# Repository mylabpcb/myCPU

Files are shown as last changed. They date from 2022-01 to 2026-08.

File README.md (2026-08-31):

> This release is obsolete, use only for learning purposes. We are working on the myCPU16 R2 with many improvements.

### Welcome to the myCPU project!.

All information is on the project site at: 
<a href="https://mycpu.mylabpcb.com/" target="_blank">myCPU project site (https://mycpu.mylabpcb.com/)</a>

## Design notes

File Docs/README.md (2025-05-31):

### Technical documentation of the myCPU Project

Here you can find all the schematics, dimensional views, BOM and assembly lists related to each module of myCPU. Including separated route views for each pcb layer.

All of this documentation is included in the printable version of the myCPU Book.

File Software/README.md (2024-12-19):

### Useful software tools to manage and configure myCPU.

Under the EncoderCLI folder you can find the Command Line tool to generate a binary file with the encoded microprogramming from the myCPU ISA definition file. 

You can use that file to write the encoded microprogramming, generated by the Encoder CLI, to the Instruction Decoder memories using an EEProm programmer or to write the simulator decoder memories.

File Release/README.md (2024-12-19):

### Useful check list about myCPU16 final release versions
This list shows the final PCB release versions of the myCPU, is useful to track the Kit release in case of updated releases of existing PCBs.

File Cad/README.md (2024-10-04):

### Useful CAD designs of tools and build help parts for myCPU

All are prepared for 3D print.

Unplugger tool is essential to manage myCPU modules when unplug from the main base stucture.
Separators are needed to build a rigid myCPU structura capable to support the modules exchange.
Display separator are used to isolate electrically the displays from the modules.

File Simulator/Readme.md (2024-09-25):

### Logisim Evolution myCPU simulator

1 For use customasm with logisim to create memory binaries from assembly code
```
customasm -f logisim8

```

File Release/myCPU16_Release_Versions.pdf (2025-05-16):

BUS Module 11 | Layout/Single Connector 5/3
RESET IO 11 | BUS Manager 9
CSM 10 | CLOCK 23
I.DECODER 9 | PC 15
FLAGS/SEQ 14 | I.REGISTER 11
REG C 8 | REG A 10
MAR 5 | ALU 19
SRAM 15 | REG B 10
DISPLAY 4 DIG 16 | OUTPUT REG 6
PROTOBOARDS 4,4,2,7 | DISPLAY LED 8b/16b 2/5

# myCPU 16

Final Release 16/05/2025

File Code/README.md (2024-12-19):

### Code programs to write the myCPU EEProms

Here you can find programs to write the myCPU EEProms using the EEProm programmer tool provided in the Kit. 

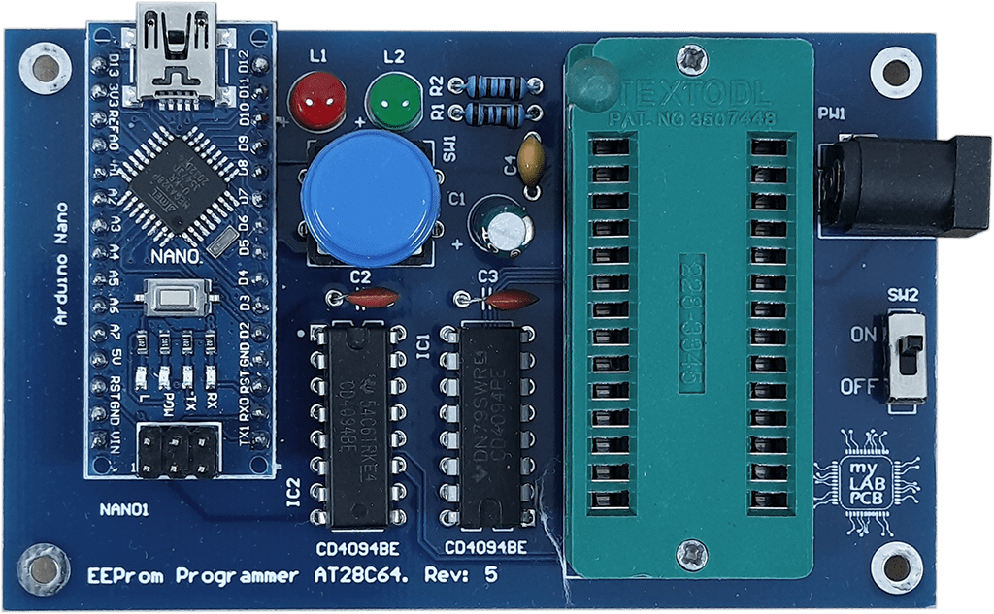
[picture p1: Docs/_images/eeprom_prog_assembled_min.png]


There are versions to write the encoded code for the functionality of the Binary to Dex/Hex Displays and the encoded microprogramming for the Instruction Decoder memories.

Provided in both versions: Arduino and Platform IO.

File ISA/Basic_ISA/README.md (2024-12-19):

### The Basec myCPU16 ISA documents
This is the default ISA for the myCPU16 project.

Here is the Basic myCPU16 Instruction Set (**ISA**) definition file with the output files generated with the **myCPU EncoderCLI**.
The "json" file is the definition file. The "bin" file is the compiled file to write to the EEProm memory and the "dat" file is for checking purposes.

There's another "dat" file with headers for better readability.

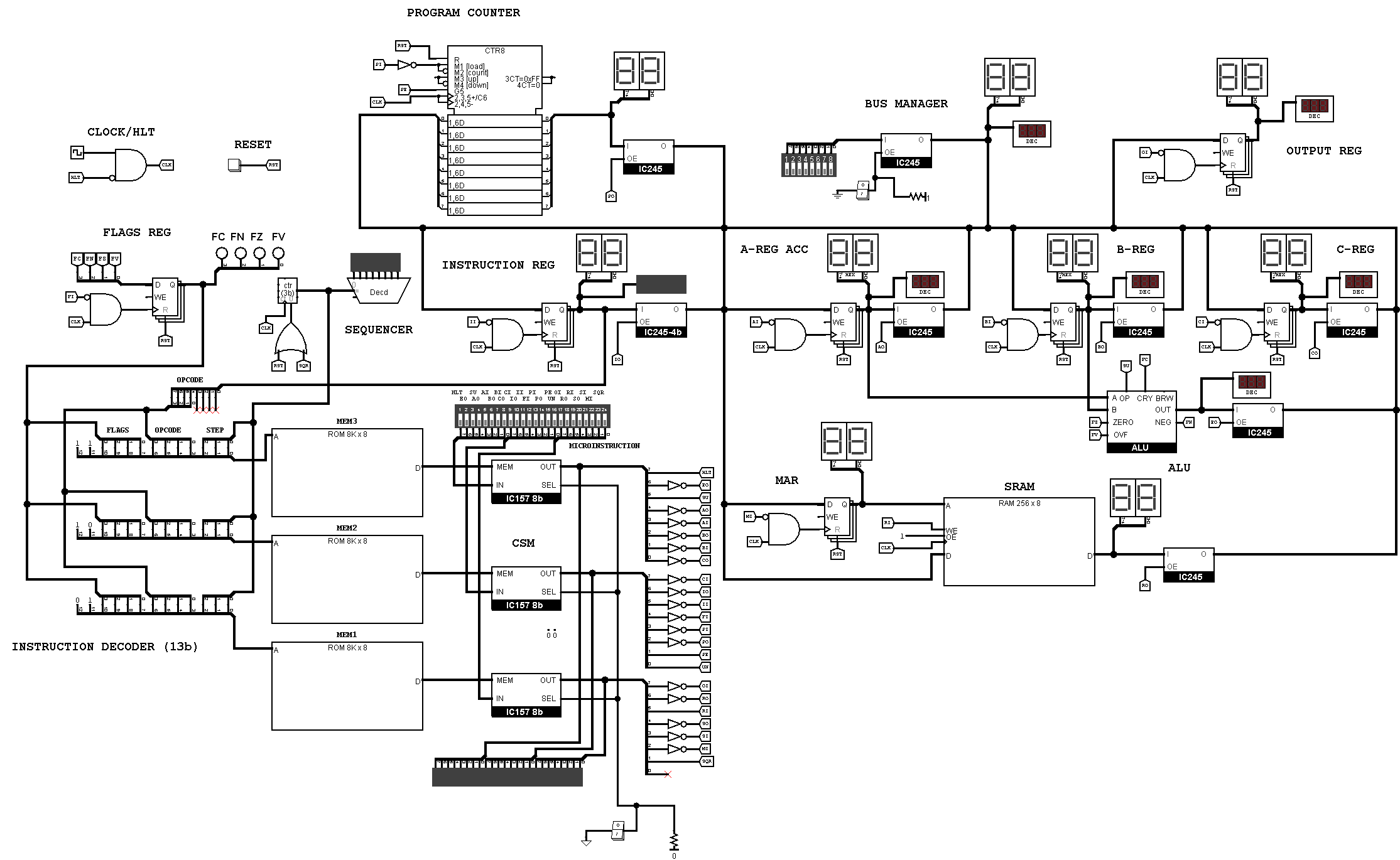
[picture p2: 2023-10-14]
Simulator/myCPU16_Sim.png

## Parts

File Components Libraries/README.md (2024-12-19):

### myCPU components libraries for some CAD IDEs

There's only Altium Designer version at this moment.

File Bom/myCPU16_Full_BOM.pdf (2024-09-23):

Chapter 4. The Components

### 4.1 myCPU BOM List

Bellow you can find the full BOM list of myCPU.

Table 4.1: myCPU Semiconductors

Description | Value | Q
+5v Voltage regulator | LM7805 | 10
555 Timer | NE555 | 8
Non inverting BUS Transceiver | 74xx245 | 9
4-bits sync counter | 74xx161 | 8
2 Line to 1 line, 4-bit data selector | 74xx157 | 4
4-bits D-Type register with 3-state outputs | 74xx173 | 11
3 to 8 lines decoder/demultiplexer | 74xx138 | 1
Dual 2 to 4 lines decoder/demultiplexer | 74xx139 | 5
TTL SRAM 64x1 with inverted outputs | 74LS189 | 2
4-bits full adder with fast carry | 74xx283 | 2
Quad 2 input NAND gates | 74xx00 | 2
Quad 2 input NOR gates | 74xx02 | 1
Hex inverters | 74xx04 | 6
Quad 2 input AND gates | 74xx08 | 2
Quad 2 input OR gates | 74xx32 | 2
Quad 2 input XOR gates | 74xx86 | 2
8-bits shift register | CD4094 | 2
EEProm 64K 8Kx8 | AT28C64 | 8
Rectifier Diode 20v 1A | 1N5817 or 1N4007 | 2
Fast Switch Diode | 1N4148 | 2

Table 4.2: myCPU Capacitors

Description | Value | Q
Electrolytic capacitor 16v or 50v | 0.22 µF | 1
Electrolytic capacitor 16v or 50v | 0.47 µF | 18
Electrolytic capacitor 16v or 50v | 1 µF | 2
Electrolytic capacitor 16v or 50v | 10 µF | 16
Electrolytic capacitor 16v or 50v | 330 µF | 4
Ceramic or Tantalum capacitor | 10 nF | 8
Ceramic or Tantalum capacitor | 100 nF | 90
Ceramic or Tantalum capacitor | 470 nF | 1

62

myCPU BOM List

Table 4.3: myCPU Resistors

Description | Value | Q
Resistors Array | 220Ω | 4
Resistors Array | 330Ω | 6
Resistors Array | **1K | 20
Resistors Array | *1.2K | 10
Resistors Array | *2.2K | 10
Resistors Array | *3.3K | 10
Resistors Array | *4.7K | 10
Variable resistor horizontal | 500K | 5
Vertical Trimmer | 1K | 1
Resistor Axial 1/4W | 220Ω | 4
Resistor Axial 1/4W | 330Ω | 16
Resistor Axial 1/4W | 680Ω | 40
Resistor Axial 1/4W | 1K | 10
Resistor Axial 1/4W | 2.2K | 4
Resistor Axial 1/4W | 4.7K | 20
Resistor Axial 1/4W | 6.8K | 2
Resistor Axial 1/4W | 100K | 2

* Number is approximated depending of the limiting resistors values used for displays

** Based on the use of 1K value for pull-down resistors on BUS modules

Table 4.4: myCPU Electromechanical

Description | Value | Q
Power Jack 3 pin center pin | 2mm | 3
Linear potentiometer (Vertical) | 1M | 1
Mini slide switch right angle, pitch 2mm | 1P2T 3 pin | 2
Mini slide switch, pitch 2mm | 1P2T 3 pin | 4
DIP Switch | 4 pos | 1
DIP Switch | 8 pos | 3
DIP Switch | 12 pos | 2
Push button | 6mm | 3
Push button | 12mm | 3

63

Chapter 4. The Components

Table 4.5: myCPU Display

Description | Value | Q
7 Segment 4 digits display red color | 0.36" | 4
7 Segment 4 digits display green color | 0.36" | 1
Bar LED 8 segments (if use 16b display modules) | *Red | 12
Led 5mm | Red | 1
Led 5mm | Green | 2
Led 5mm | Yellow | 1
Led 3mm | Blue | 21
Led 3mm | Green | 8
Led 3mm | *Red | 45

* Number depends of your preferences for the color of 8b or 16b displays.

Table 4.6: myCPU Headers, Connectors, Wire and DIP sockets

Description | Value | Q
ZIF socket 28p wide (EEprom programmer) | 28W | 1
28 pin wide socket for AT28C64 | 28p | 10
20 pin narrow socket | 20p | 10
16 pin narrow socket | 16p | 40
14 pin narrow socket | 14p | 20
8 pin narrow socket | 8p | 10
Socket header female vertical dual row | 2x16 | 20
Socket header female vertical dual row | 2x12 | 10
Socket header female vertical dual row | 2x8 | 20
Socket header female right angle dual row | 2x16 | 10
Socket header female right angle dual row | 2x8 | 10
Pin header right angle dual row | 2x40 | 20
Pin header vertical dual row | 2x40 | 30
IDC flat wire connector female dual row | 2x4 | 10
IDC flat wire connector female dual row | 2x12 | 2
Flat Ribbon Wire 1,27mm | 8 lines | 1m
*Flat Ribbon Wire 1,27mm | 34 lines | 1m

* Is difficult to find 32 lines flat wire 1.27mm

64

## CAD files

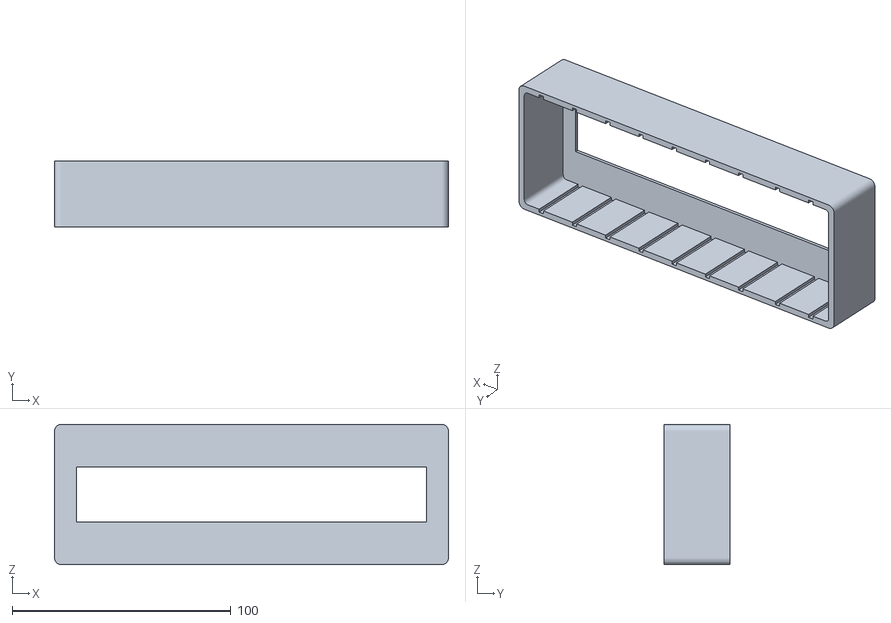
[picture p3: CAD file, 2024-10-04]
Cad/ModulesBox_Guided.stl
180.0 x 30.0 x 64.0

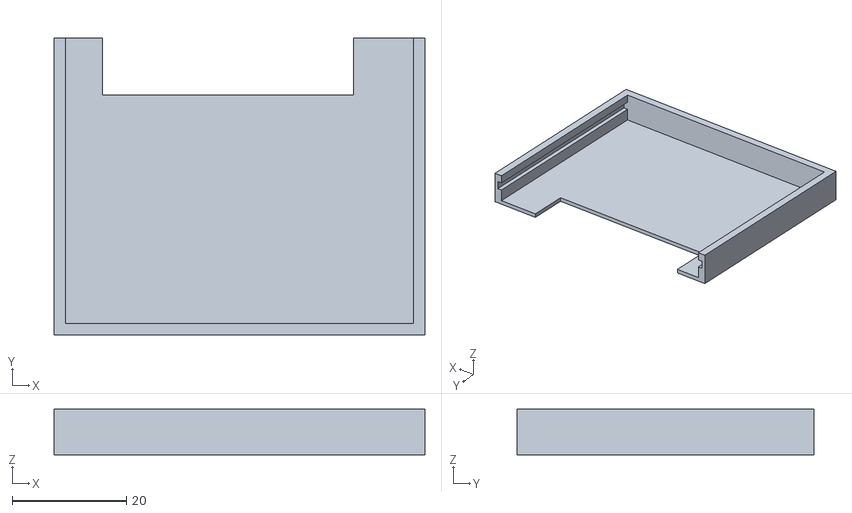
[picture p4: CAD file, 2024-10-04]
Cad/Display4D_Separator.stl
65.0 x 52.0 x 8.00

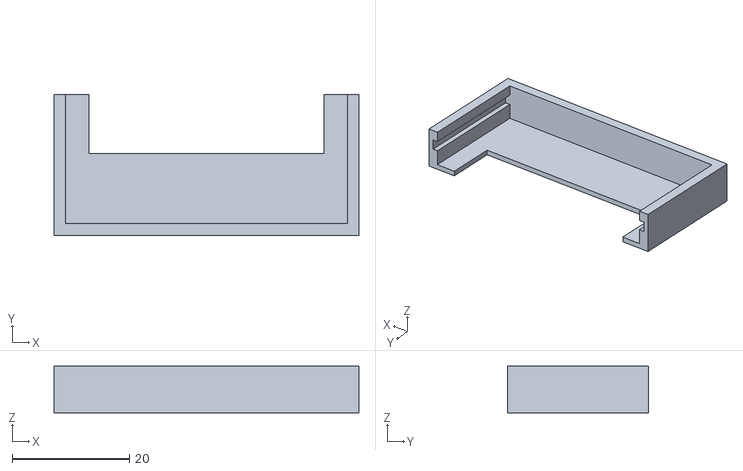
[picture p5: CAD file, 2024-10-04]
Cad/Display8_Separator.stl
52.0 x 24.0 x 8.00

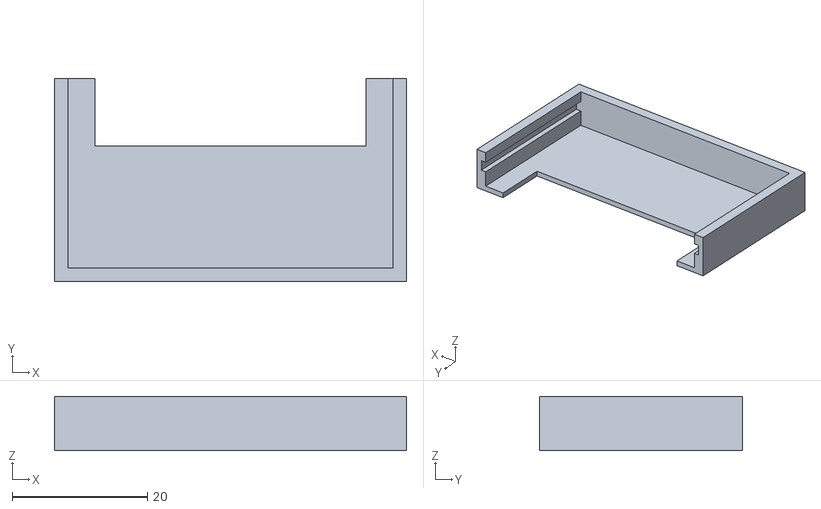
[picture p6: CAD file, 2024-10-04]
Cad/Display16_Separator.stl
52.0 x 30.0 x 8.00

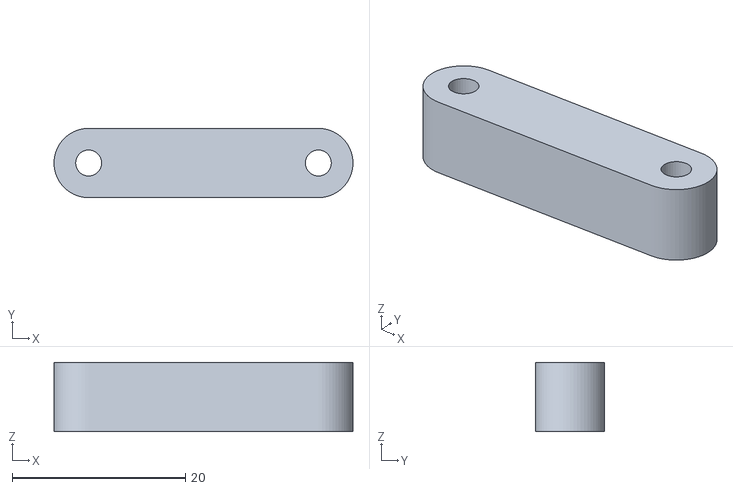
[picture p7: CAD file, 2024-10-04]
Cad/Sep2_265.stl
34.5 x 8.00 x 8.00

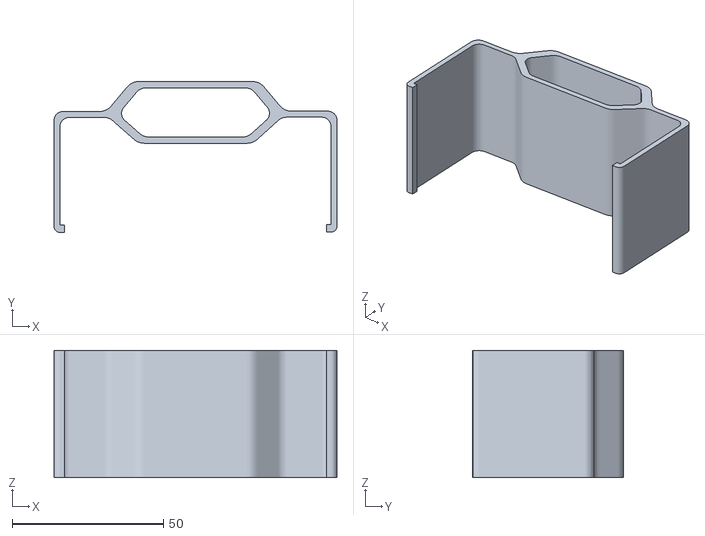
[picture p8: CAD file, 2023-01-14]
Cad/Unplugger.stl
93.5 x 49.9 x 42.0

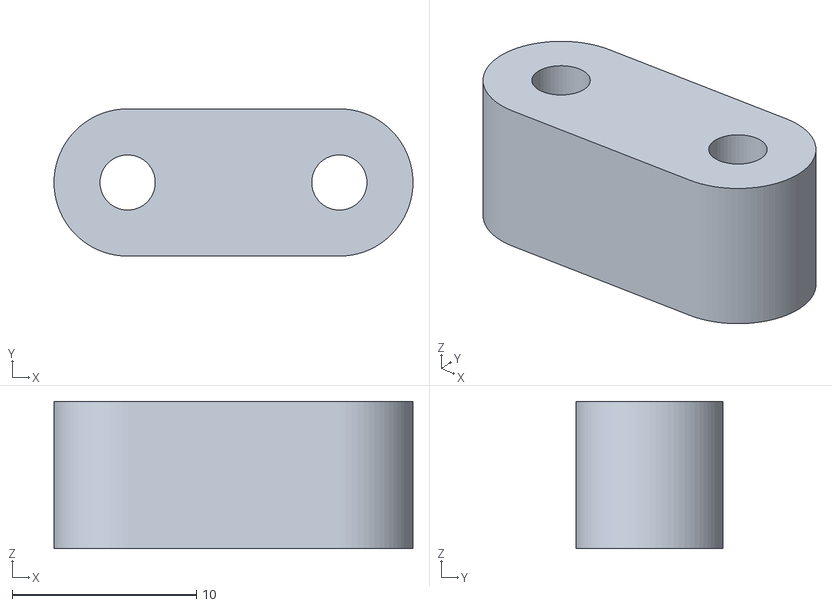
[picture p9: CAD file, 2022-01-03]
Cad/Sep2_115.stl
19.5 x 8.00 x 8.00

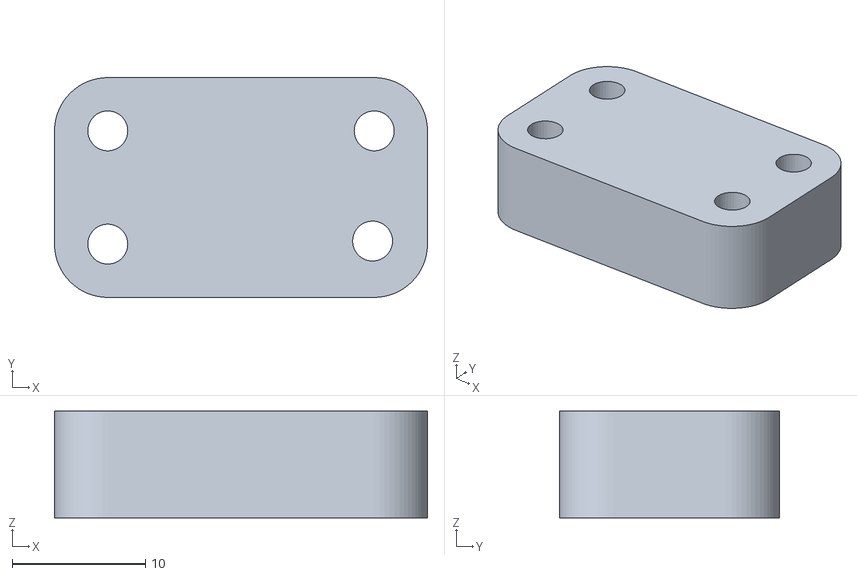
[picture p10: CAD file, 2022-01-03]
Cad/Sep4_200.stl
28.0 x 16.5 x 8.00

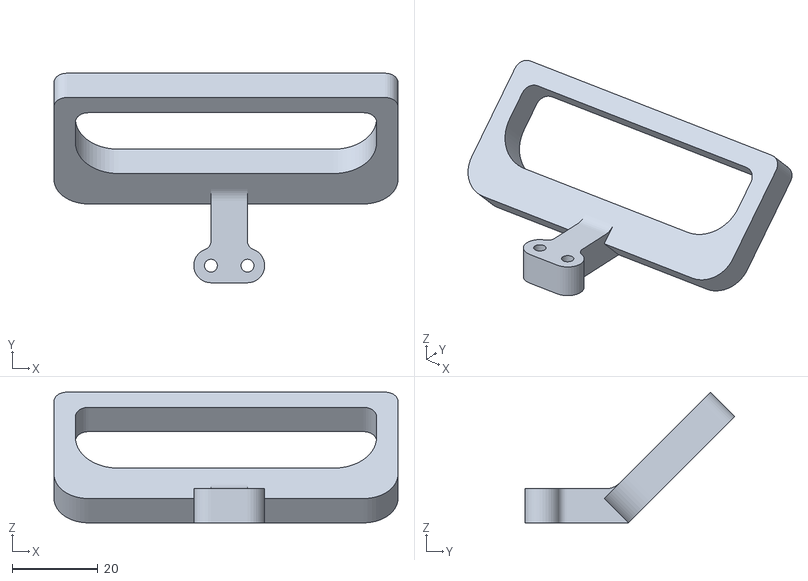
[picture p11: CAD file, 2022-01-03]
Cad/Handle_85.stl
80.0 x 48.7 x 30.4

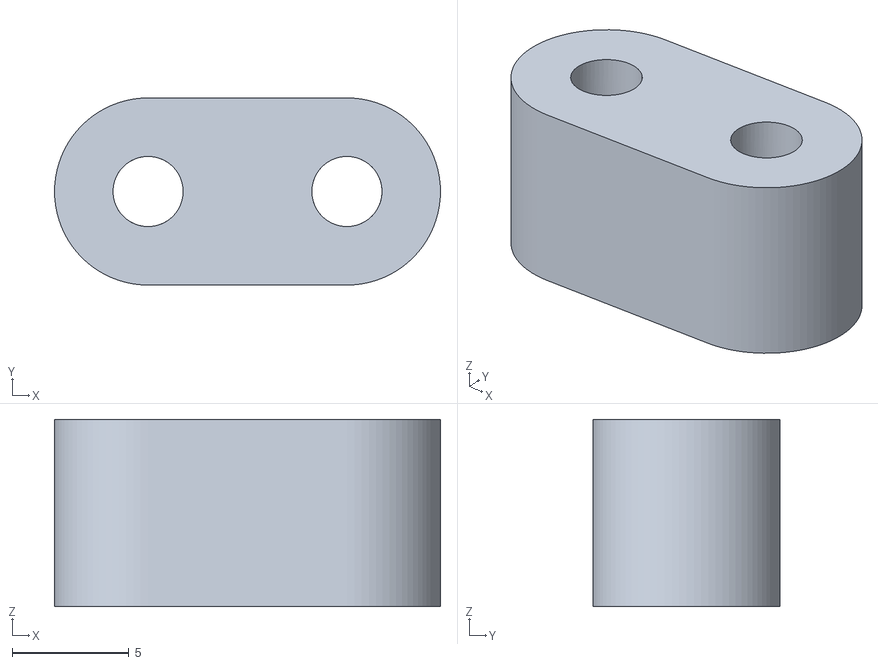
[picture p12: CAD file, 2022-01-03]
Cad/Sep2_85.stl
16.5 x 8.00 x 8.00

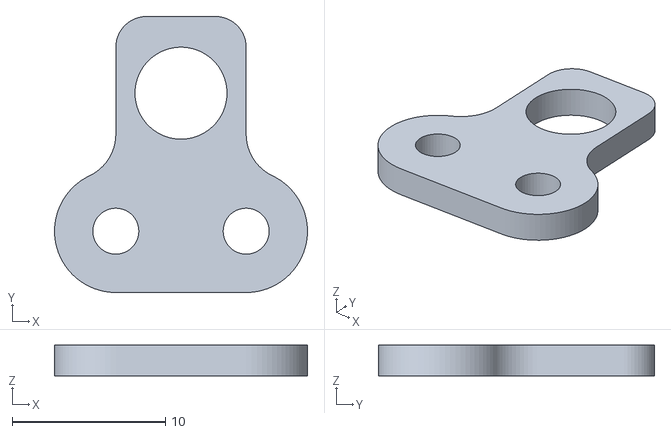
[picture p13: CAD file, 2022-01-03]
Cad/Sep2_85_Wall.stl
16.5 x 18.0 x 2.00

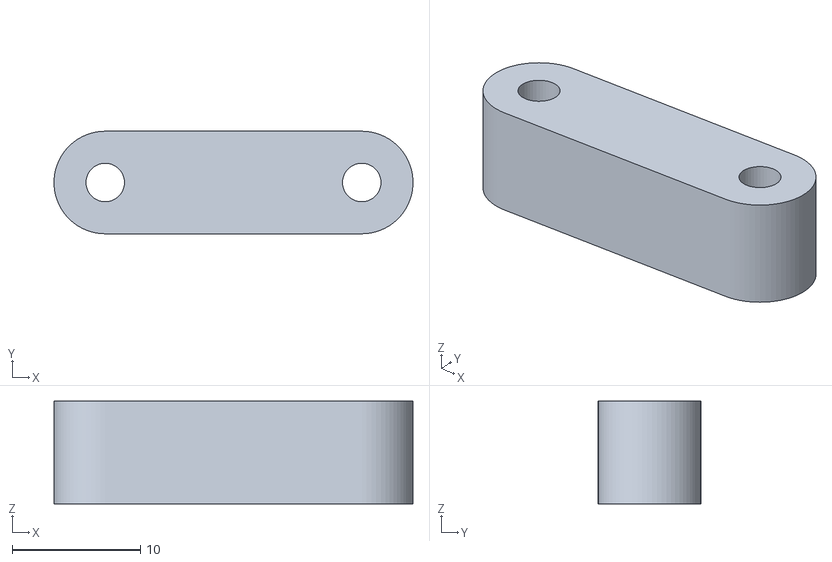
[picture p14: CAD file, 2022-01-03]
Cad/Sep2_200.stl
28.0 x 8.00 x 8.00

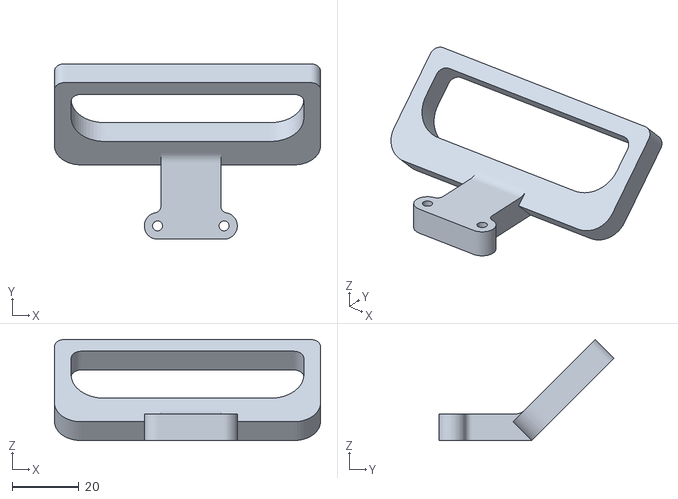
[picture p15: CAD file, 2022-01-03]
Cad/Handle_180.stl
80.0 x 52.7 x 30.4

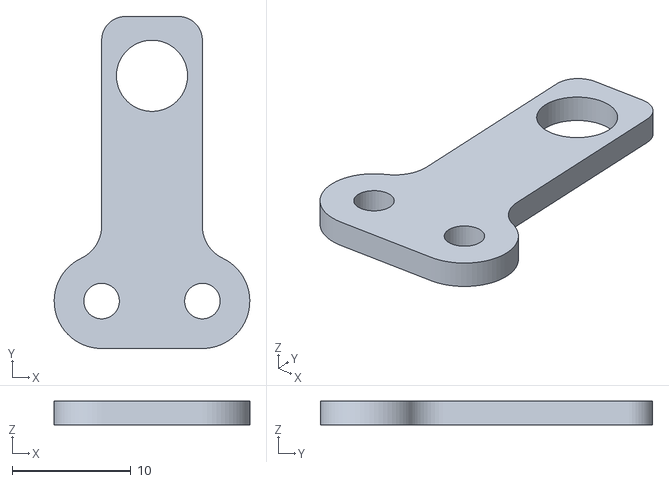
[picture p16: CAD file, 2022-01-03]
Cad/Sep2_180_Wall.stl
16.5 x 28.0 x 2.00

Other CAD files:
Cad/Sep2_200_Wall v2.stl
Cad/Sep3_200_Wall v3.stl
Cad/Sep.stl
Cad/Sep2_180.stl
Cad/Sep2_115_Washer.stl
Cad/Sep2_180_Washer.stl
Cad/Sep2_200_Washer.stl
Cad/Sep2_265_Washer.stl
Cad/Sep2_85_Washer.stl
Cad/Sep4_200_Washer.stl
Cad/Sep_Washer.stl

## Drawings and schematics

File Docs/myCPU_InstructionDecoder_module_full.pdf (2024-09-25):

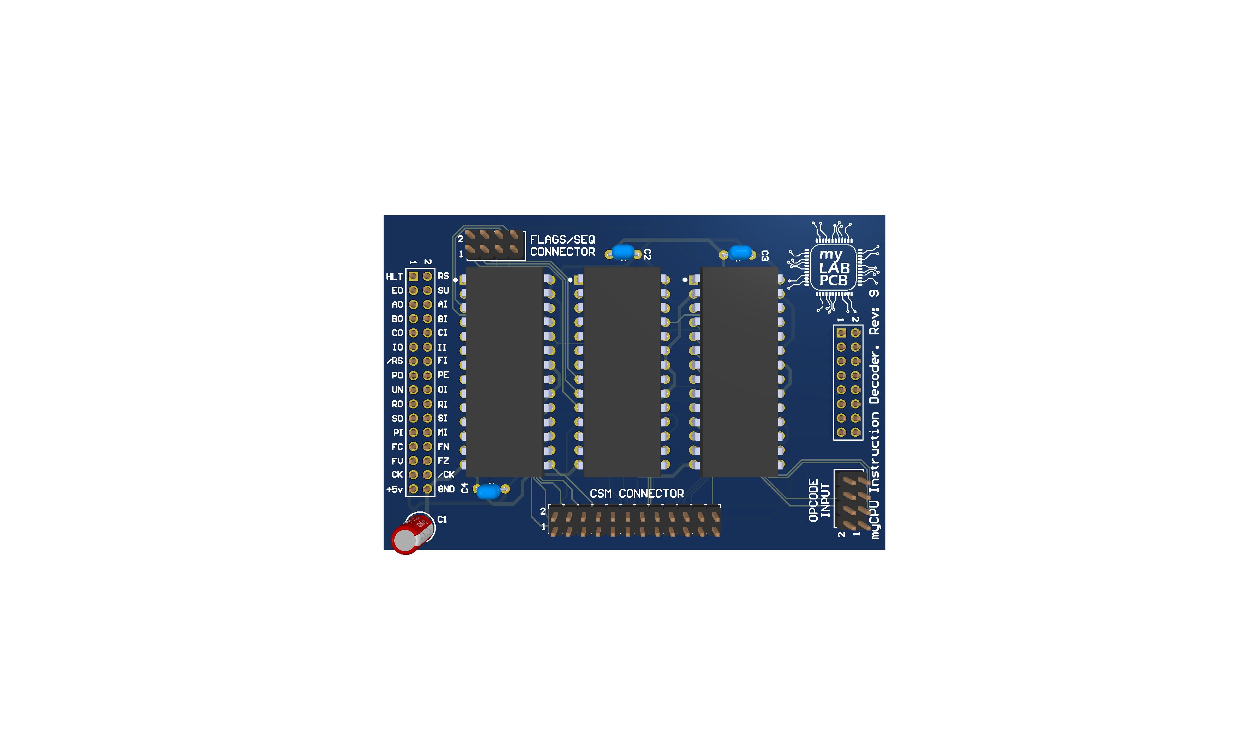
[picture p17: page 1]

Control BUS Connector | Data BUS Connector

## Instruction Register Connector

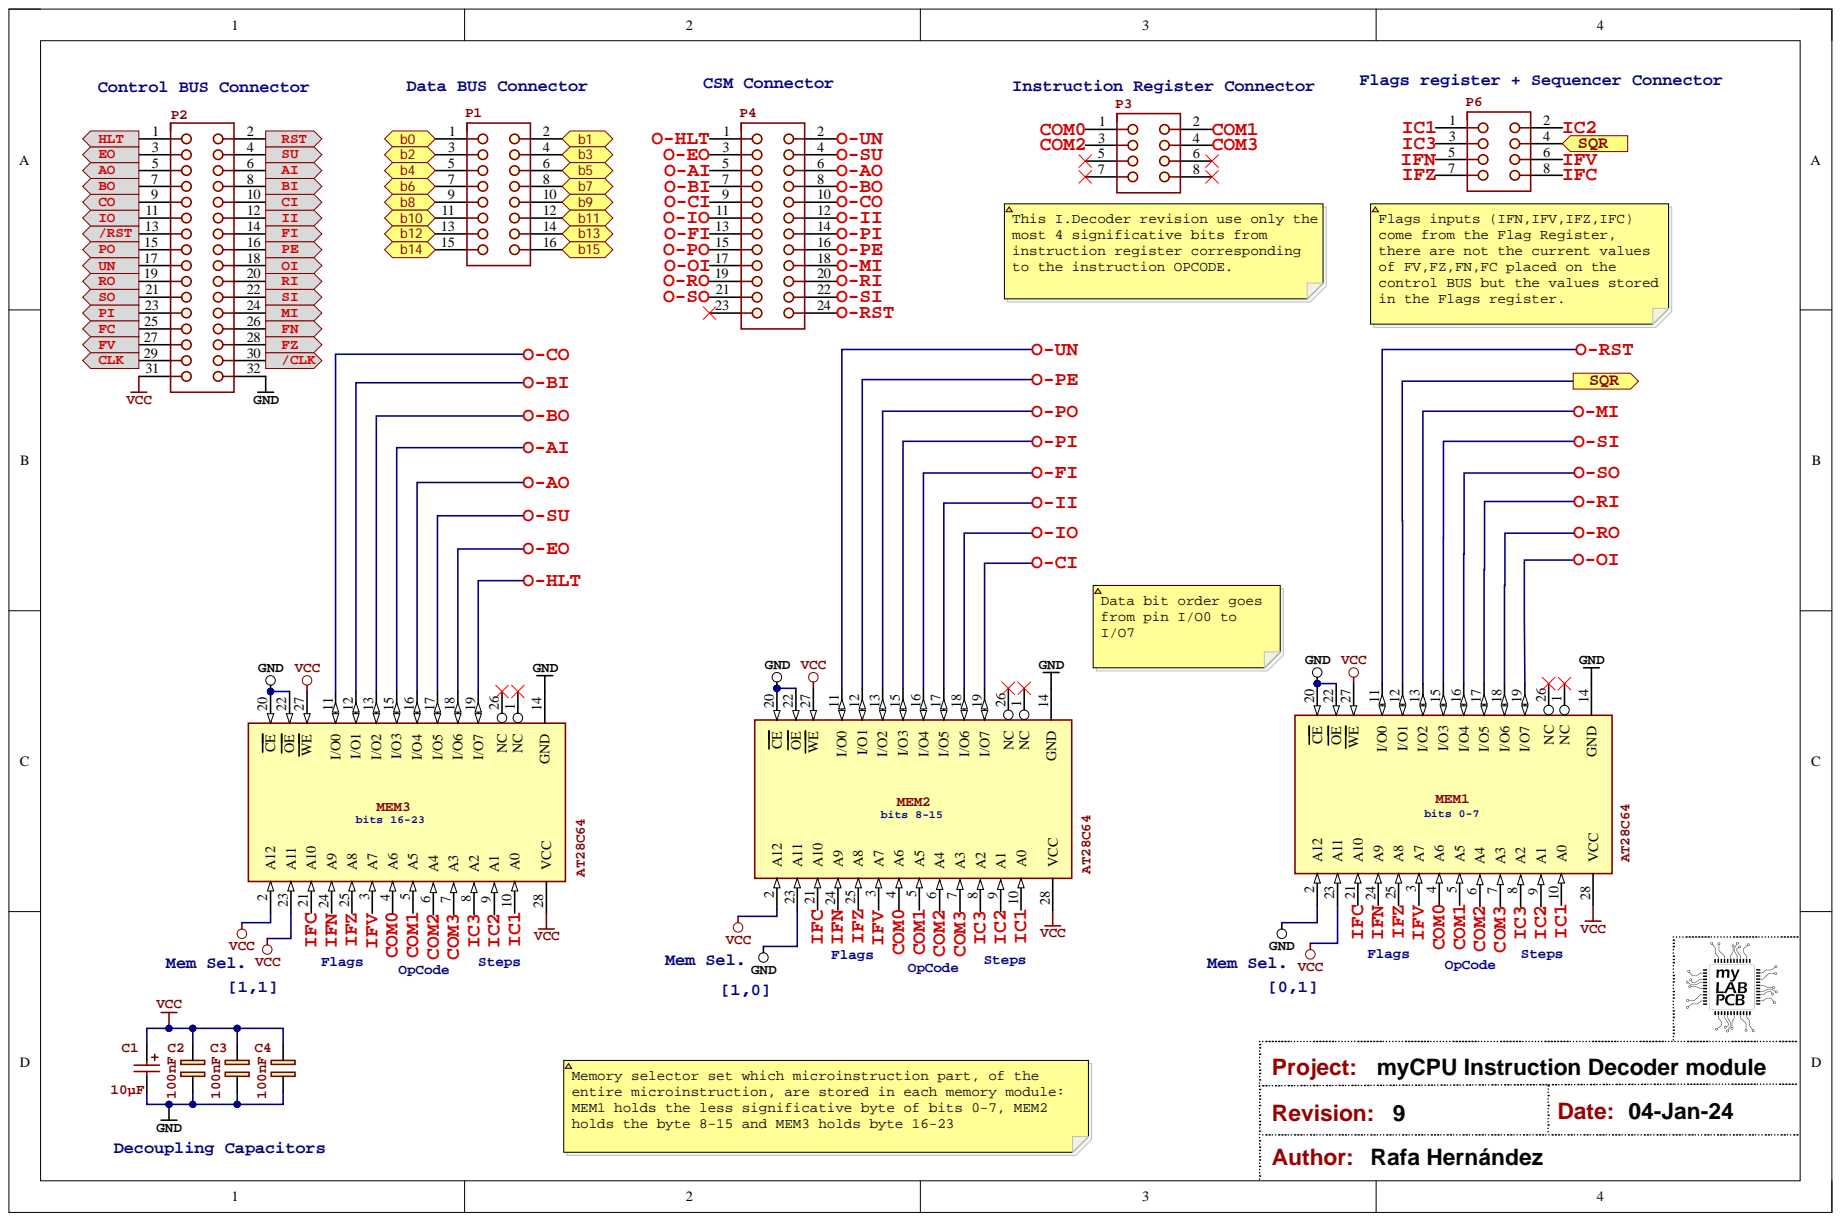
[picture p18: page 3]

Flags register + Sequencer Connector

This I.Decoder revision use only the
most 4 significative bits from
instruction register corresponding
to the instruction OPCODE.

Flags inputs (IFN,IFV,IFZ,IFC)
come from the Flag Register,
there are not the current values
of FV,FZ,FN,FC placed on the
control BUS but the values stored
in the Flags register.

Data bit order goes
from pin I/O0 to

Memory selector set which microinstruction part, of the
entire microinstruction, are stored in each memory module:
MEM1 holds the less significative byte of bits 0-7, MEM2
holds the byte 8-15 and MEM3 holds byte 16-23

Project: myCPU Instruction Decoder module

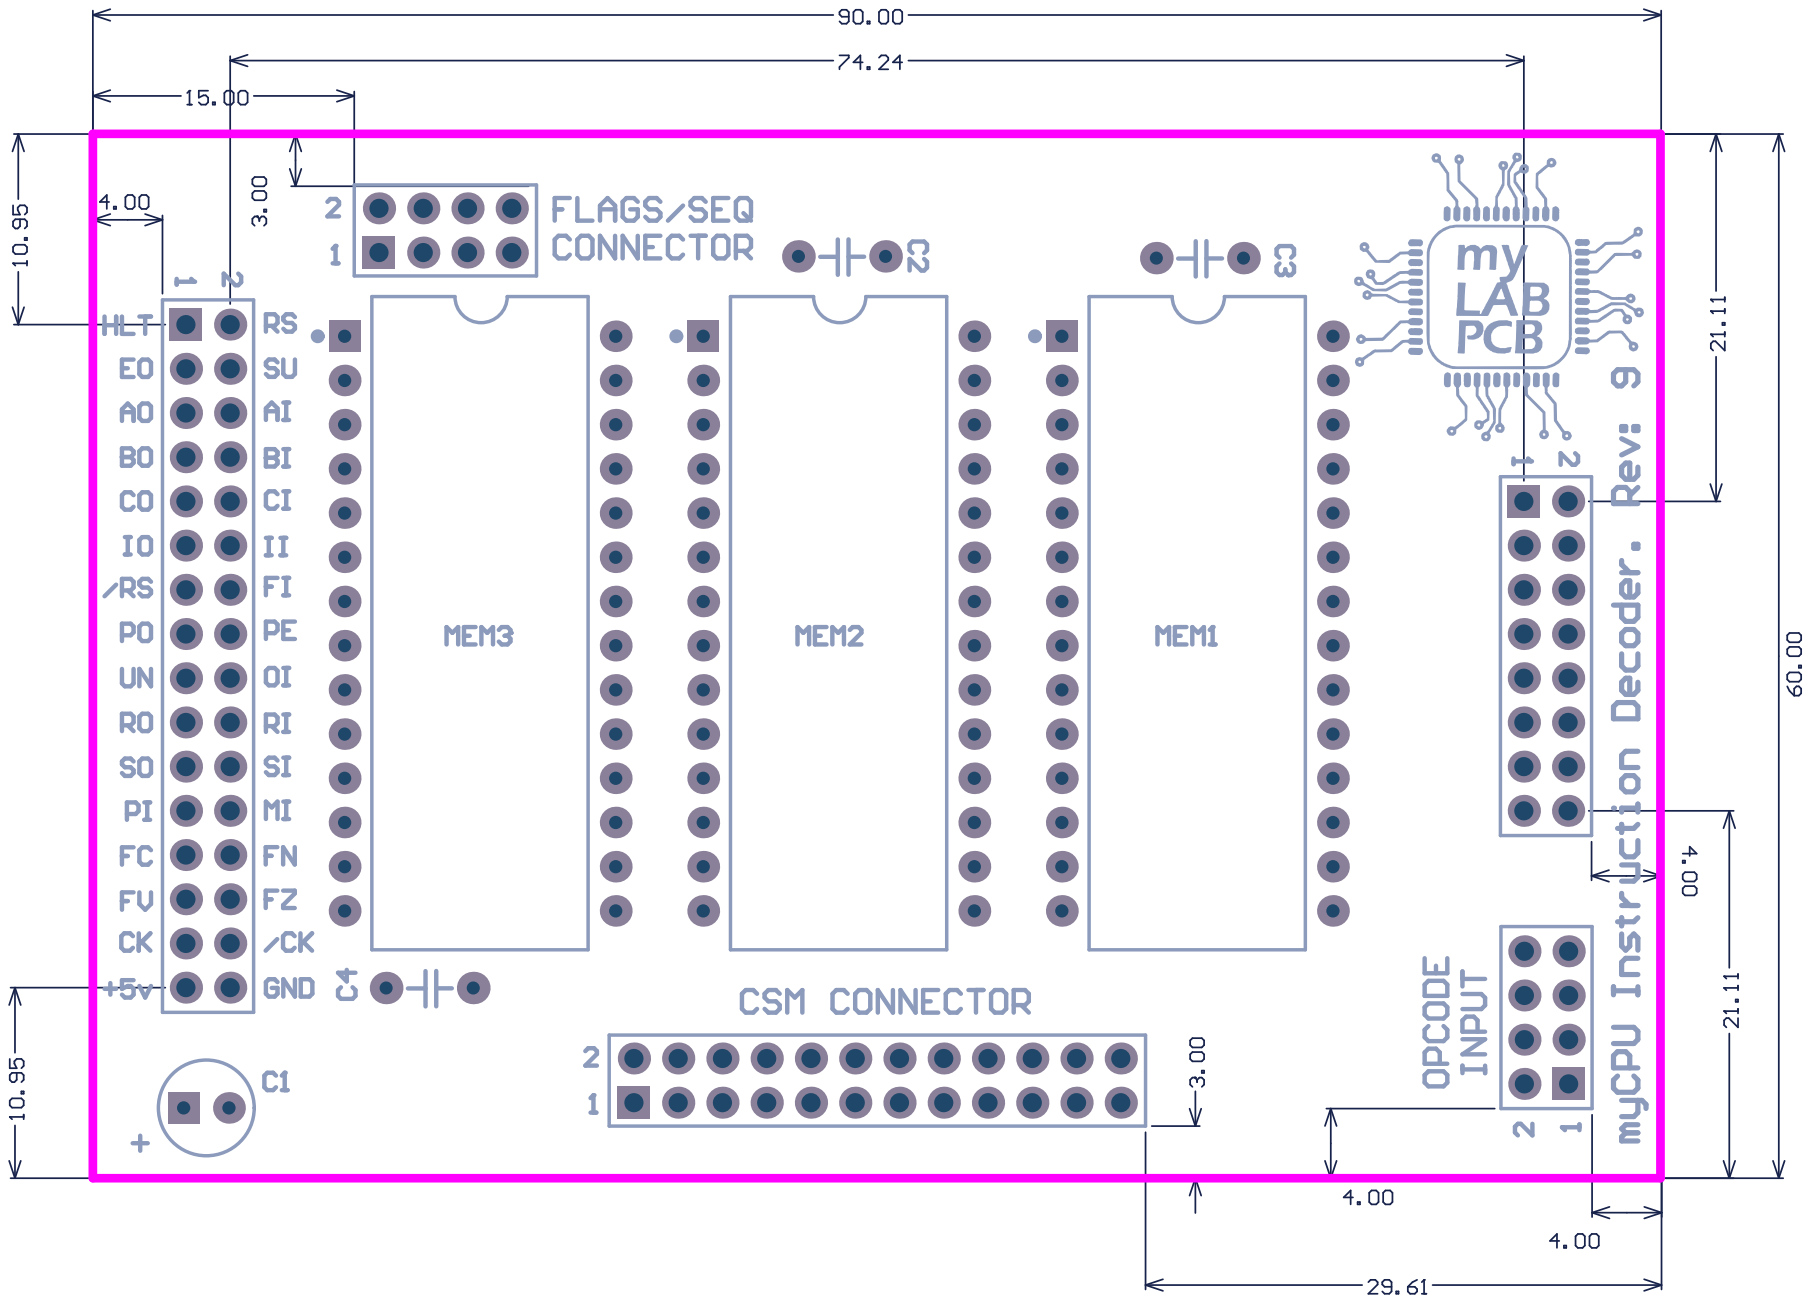
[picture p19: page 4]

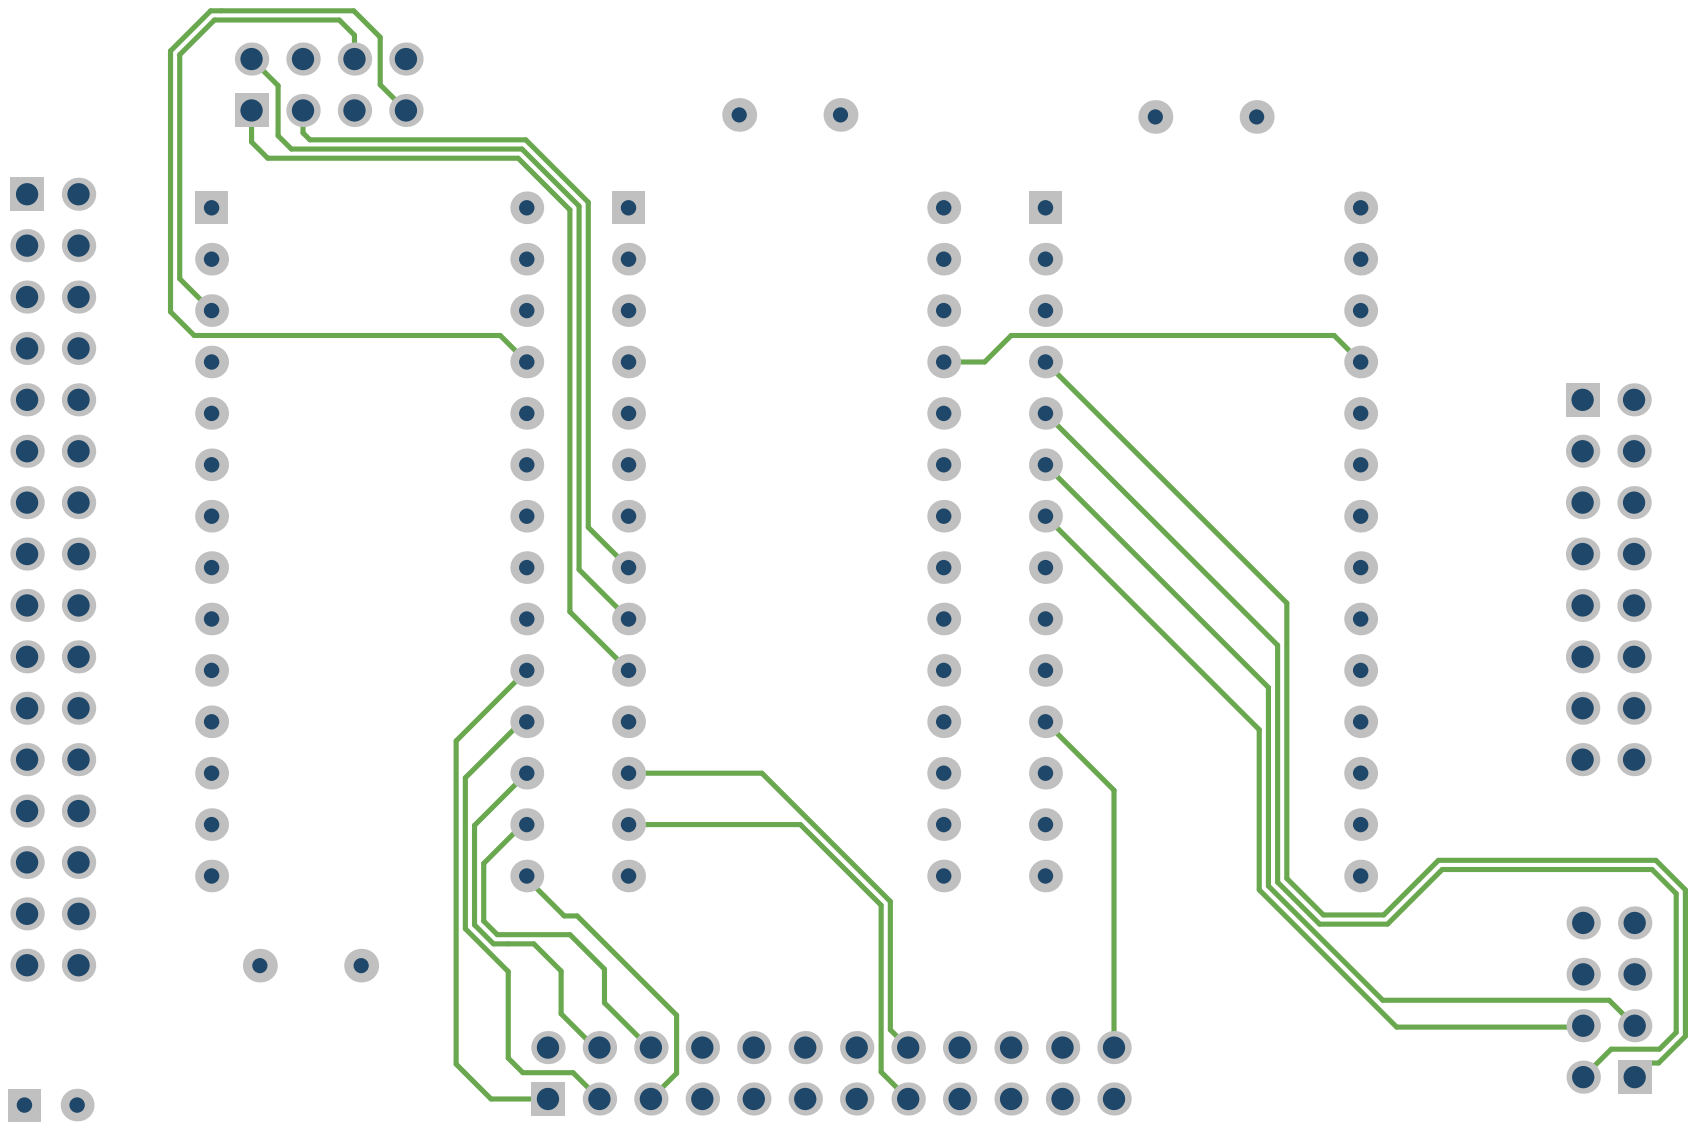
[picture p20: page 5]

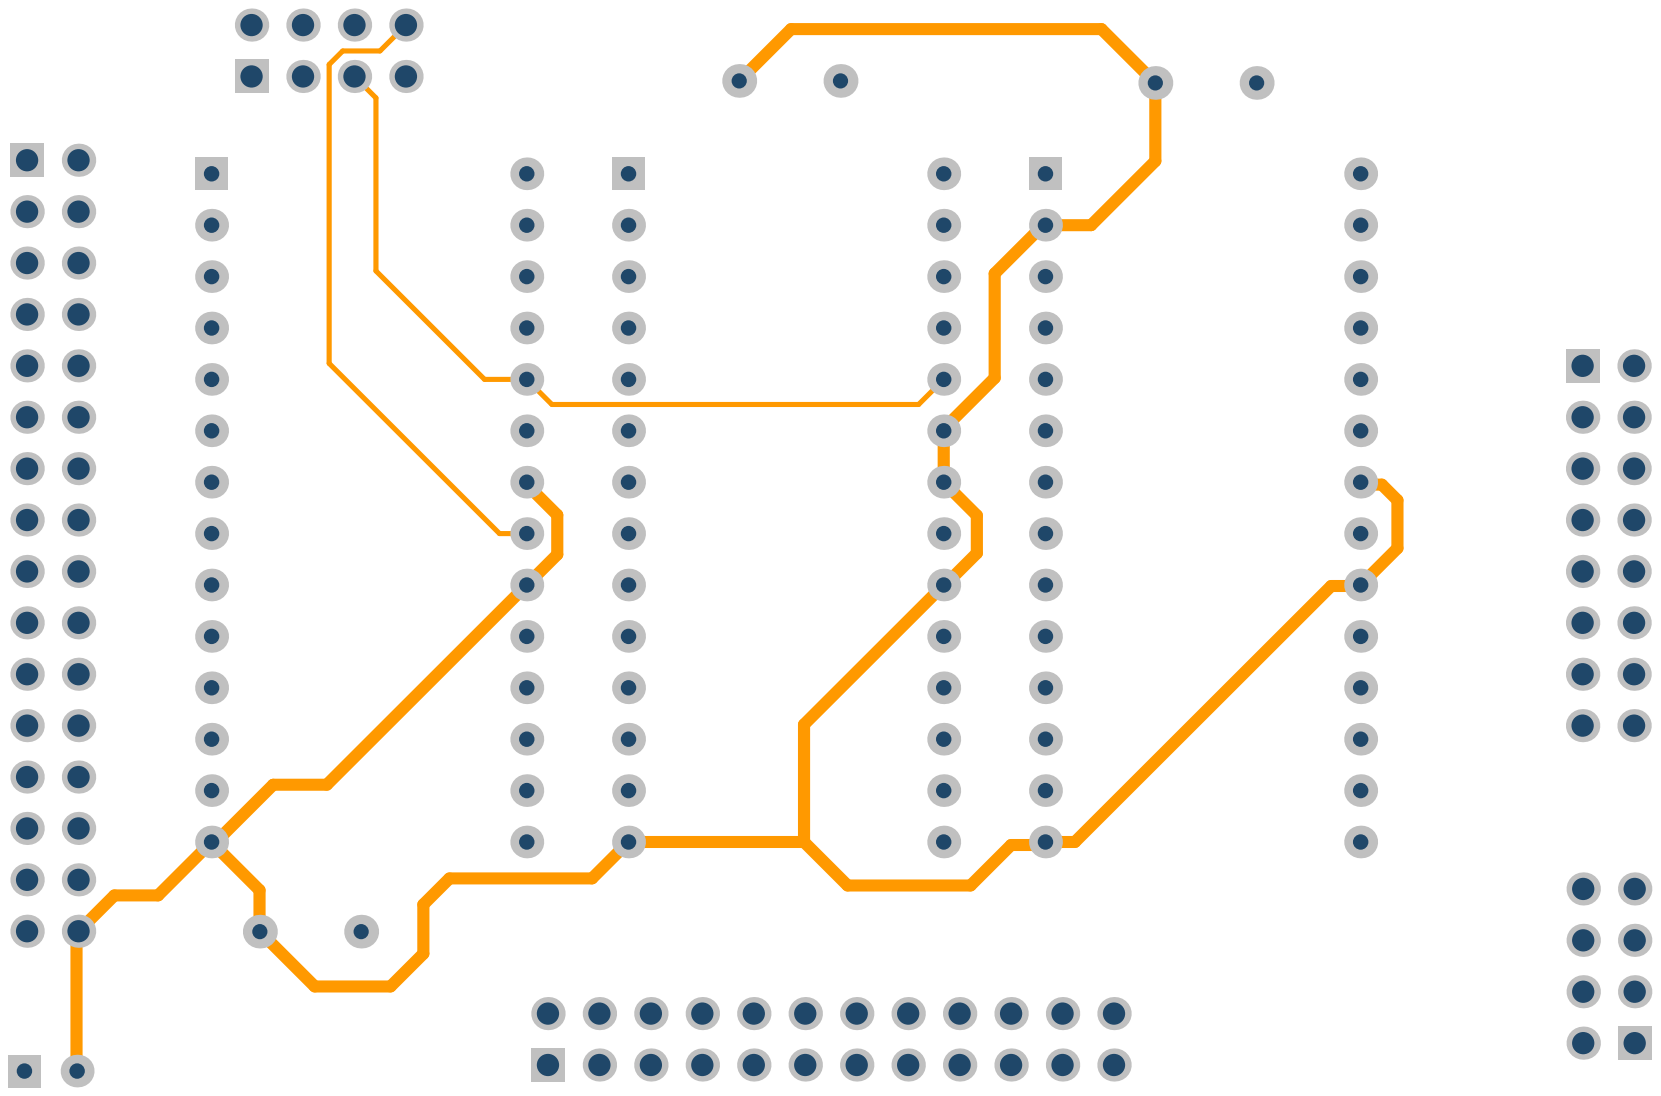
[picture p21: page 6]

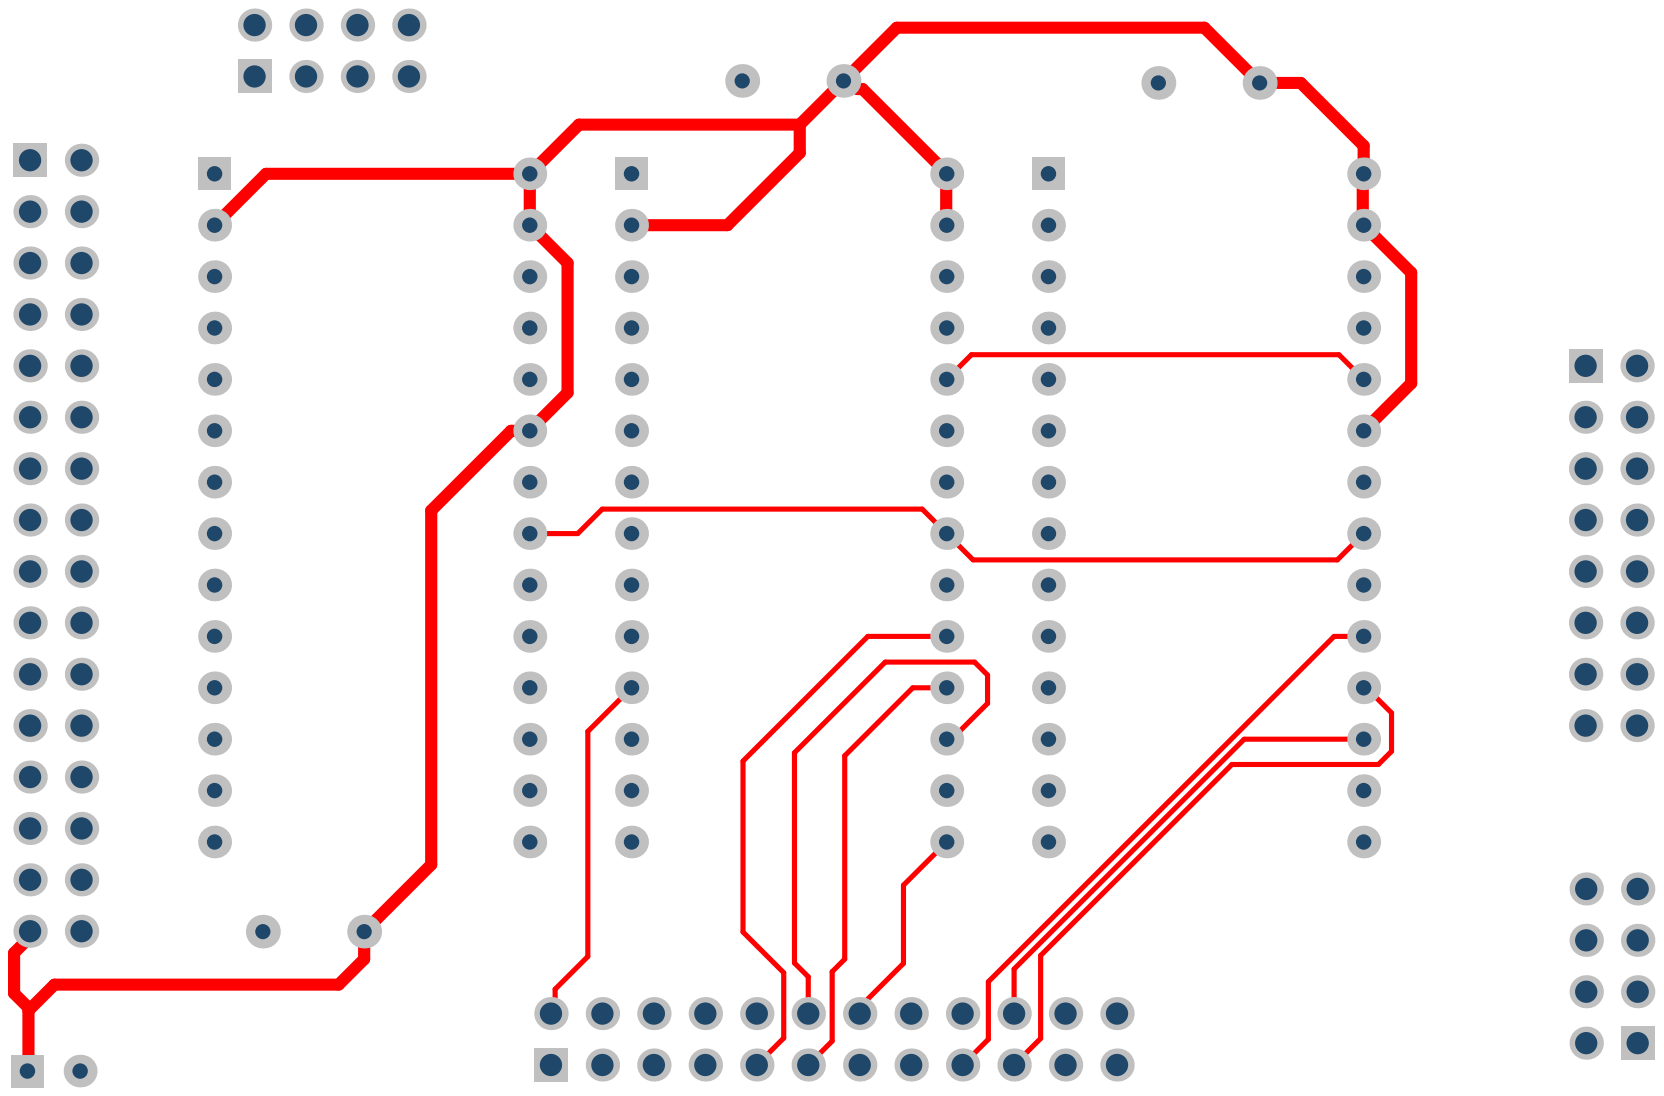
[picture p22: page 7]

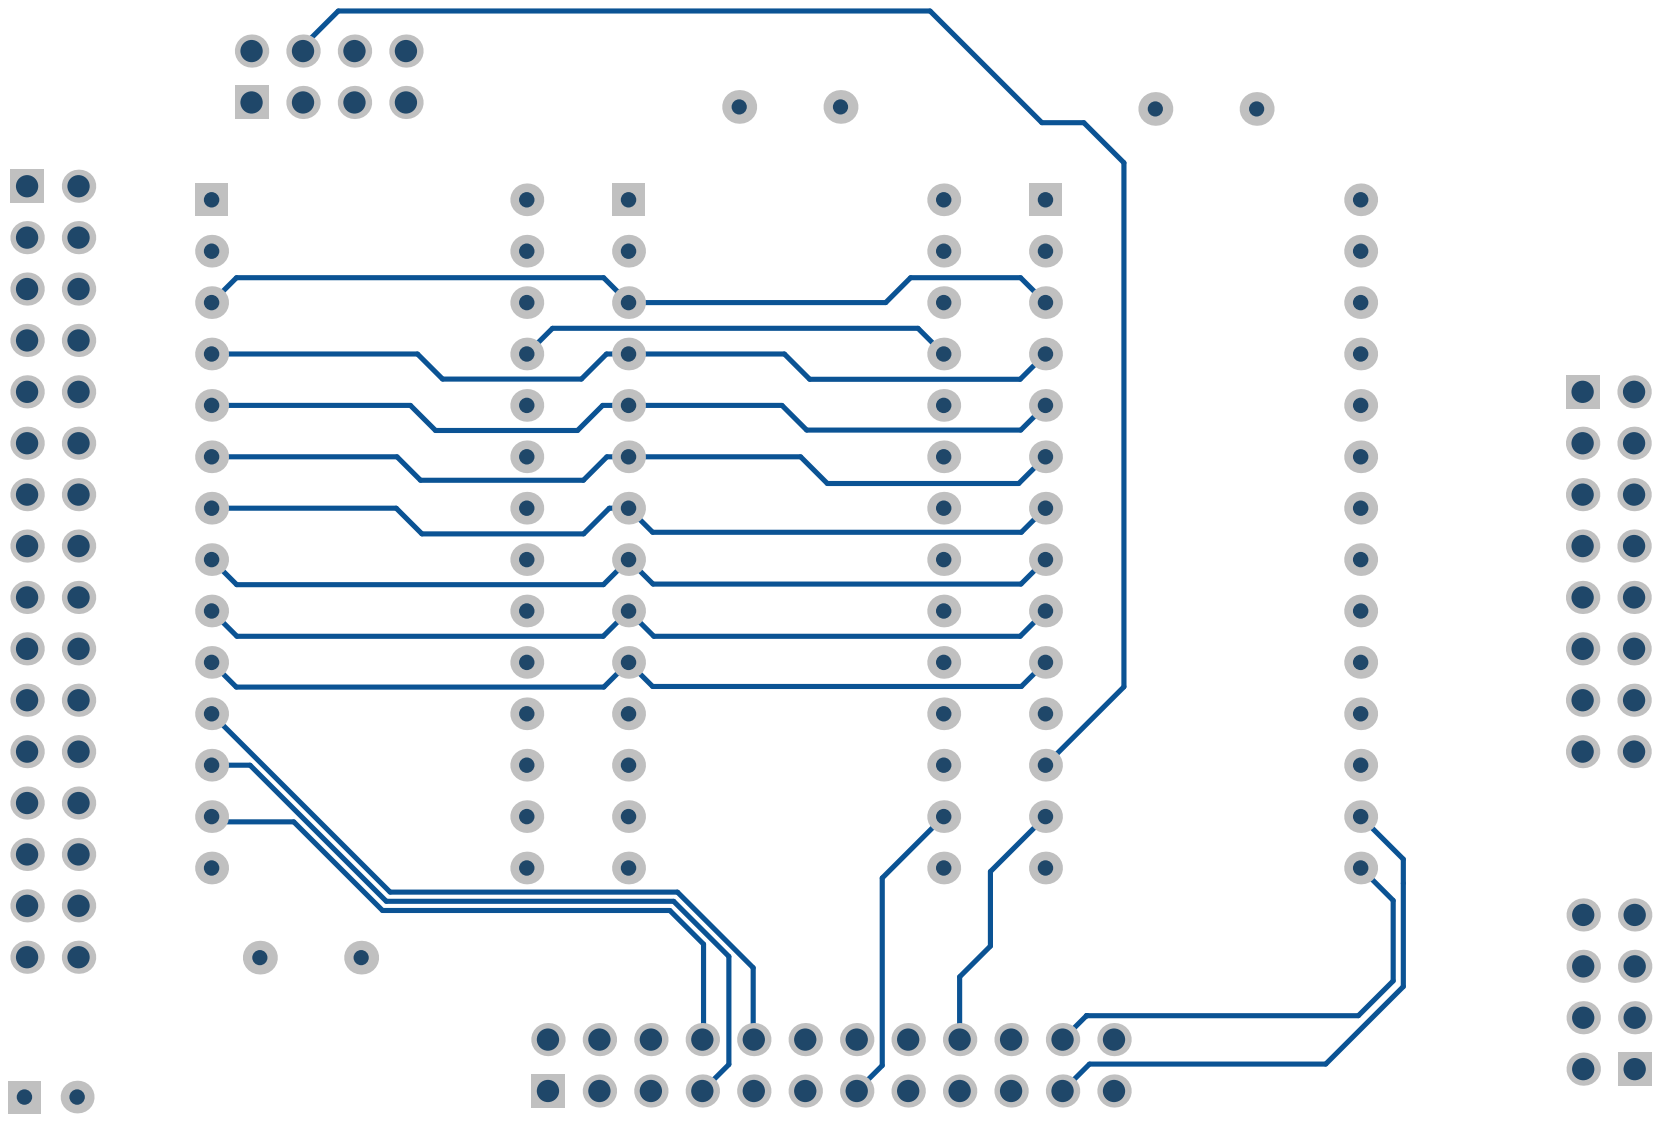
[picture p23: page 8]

# Bill of Materials

# myCPU Instruction Decoder

Description | Value | Q
Electrolytic capacitor 16v/50v | 10µF | 1
Ceramic capacitor | 100nF | 3
EEProm 64K, 8K x 8 bits | AT28C64 | 3
Pin Header, THT, pitch 2.54mm, Dual Row, Vertical | 16p | 1
Pin Header, THT, pitch 2.54mm, Dual Row, Vertical | 32p | 1
Pin Header, THT, pitch 2.54mm, Dual Row, Vertical | 8p | 2
Pin Header, THT, pitch 2.54mm, Dual Row, Vertical | 24p | 1

# Assembly List

# myCPU Instruction Decoder

Designator | Description | Value
C1 | Electrolytic capacitor 16v/50v | 10µF
C2 | Ceramic capacitor | 100nF
C3 | Ceramic capacitor | 100nF
C4 | Ceramic capacitor | 100nF
MEM1 | EEProm 64K, 8K x 8 bits | AT28C64
MEM2 | EEProm 64K, 8K x 8 bits | AT28C64
MEM3 | EEProm 64K, 8K x 8 bits | AT28C64
P1 | Pin Header, THT, pitch 2.54mm, Dual Row, Vertical | 16p
P2 | Pin Header, THT, pitch 2.54mm, Dual Row, Vertical | 32p
P3 | Pin Header, THT, pitch 2.54mm, Dual Row, Vertical | 8p
P4 | Pin Header, THT, pitch 2.54mm, Dual Row, Vertical | 24p
P6 | Pin Header, THT, pitch 2.54mm, Dual Row, Vertical | 8p

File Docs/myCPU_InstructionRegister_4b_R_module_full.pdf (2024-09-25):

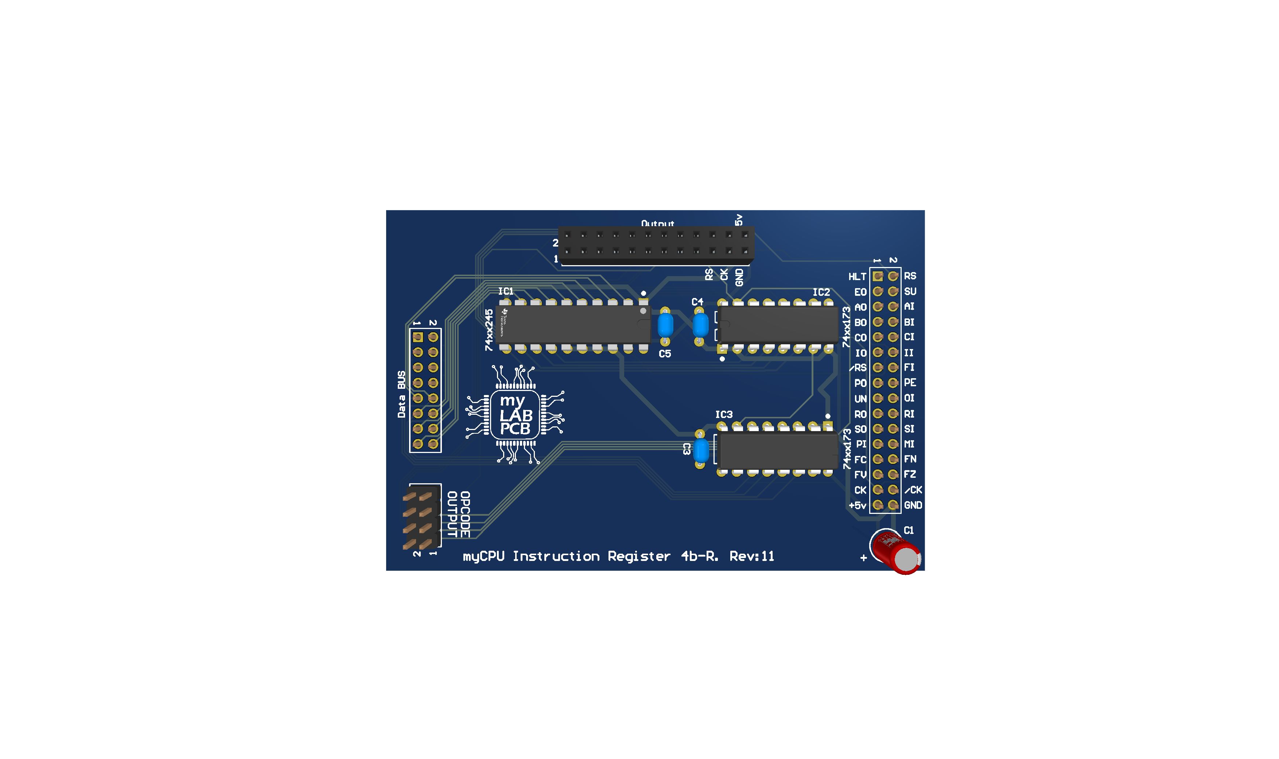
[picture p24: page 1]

Control BUS Connector | OUTPUT Connector | Data BUS Connector

### Instruction Decoder Connector

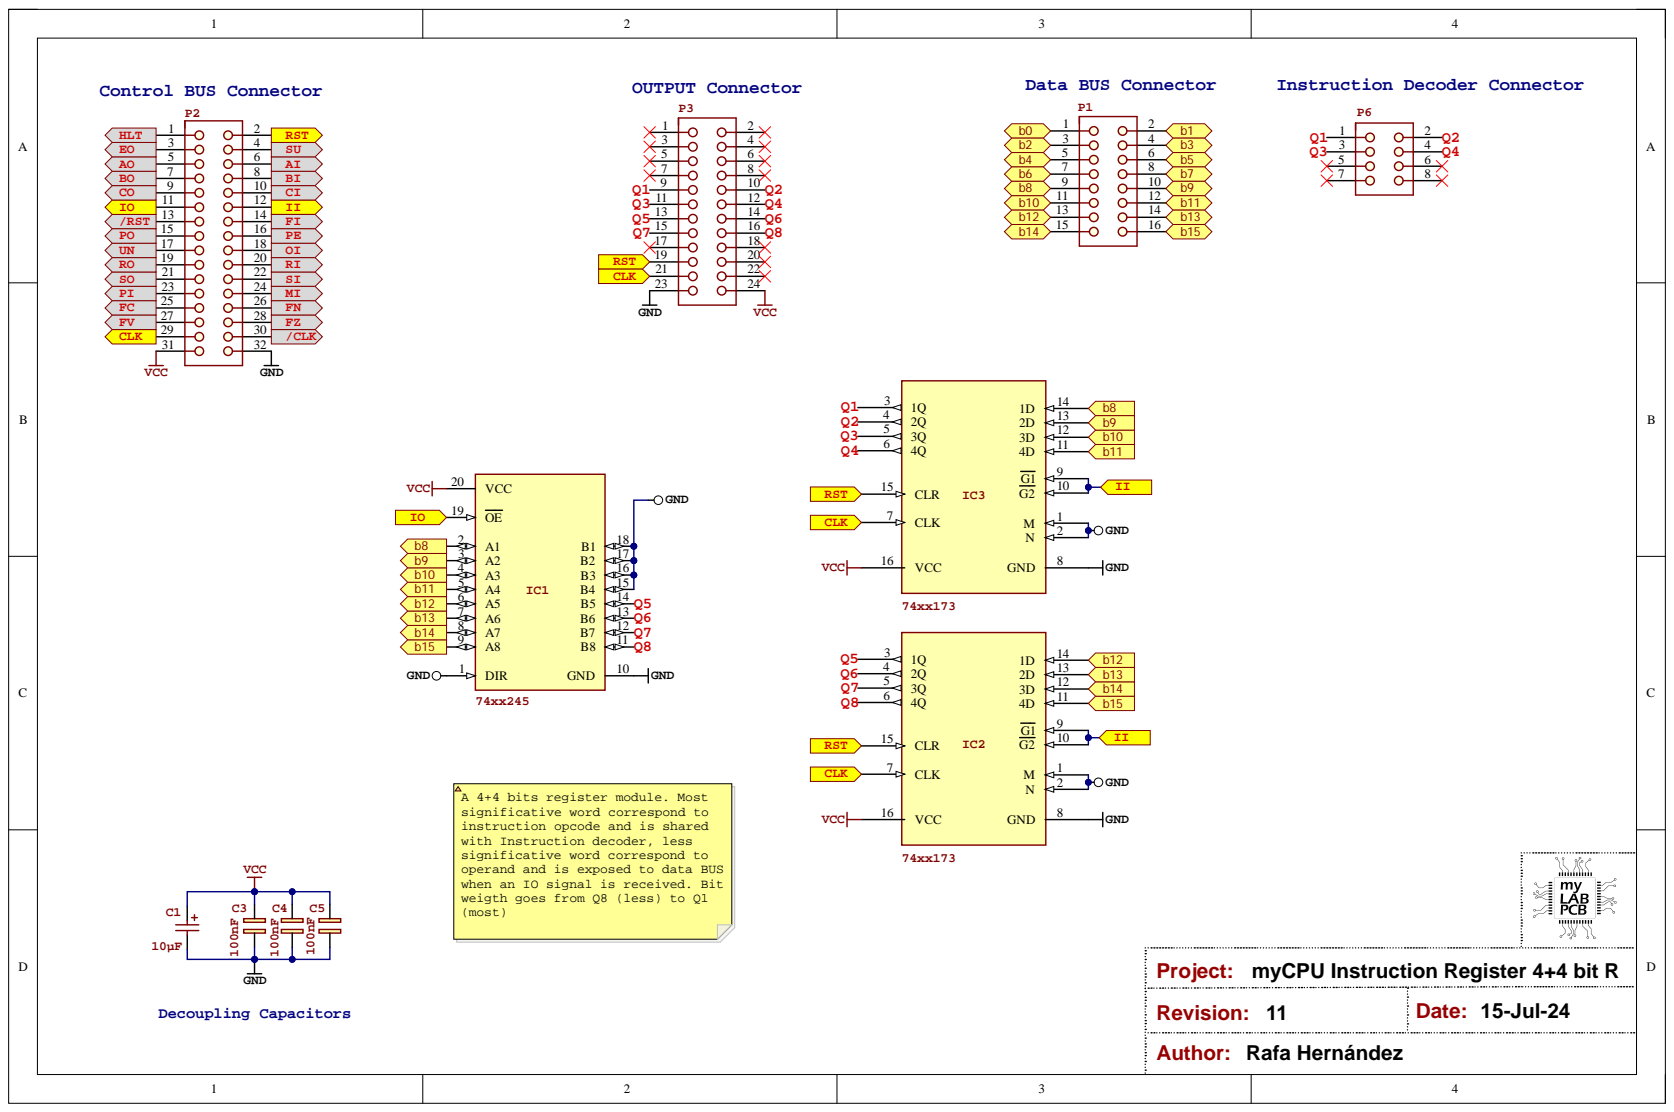
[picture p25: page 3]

A 4+4 bits register module. Most
significative word correspond to
instruction opcode and is shared
with Instruction decoder, less
operand and is exposed to data BUS
when an IO signal is received. Bit
weigth goes from Q8 (less) to Q1
(most)

Project: myCPU Instruction Register 4+4 bit R

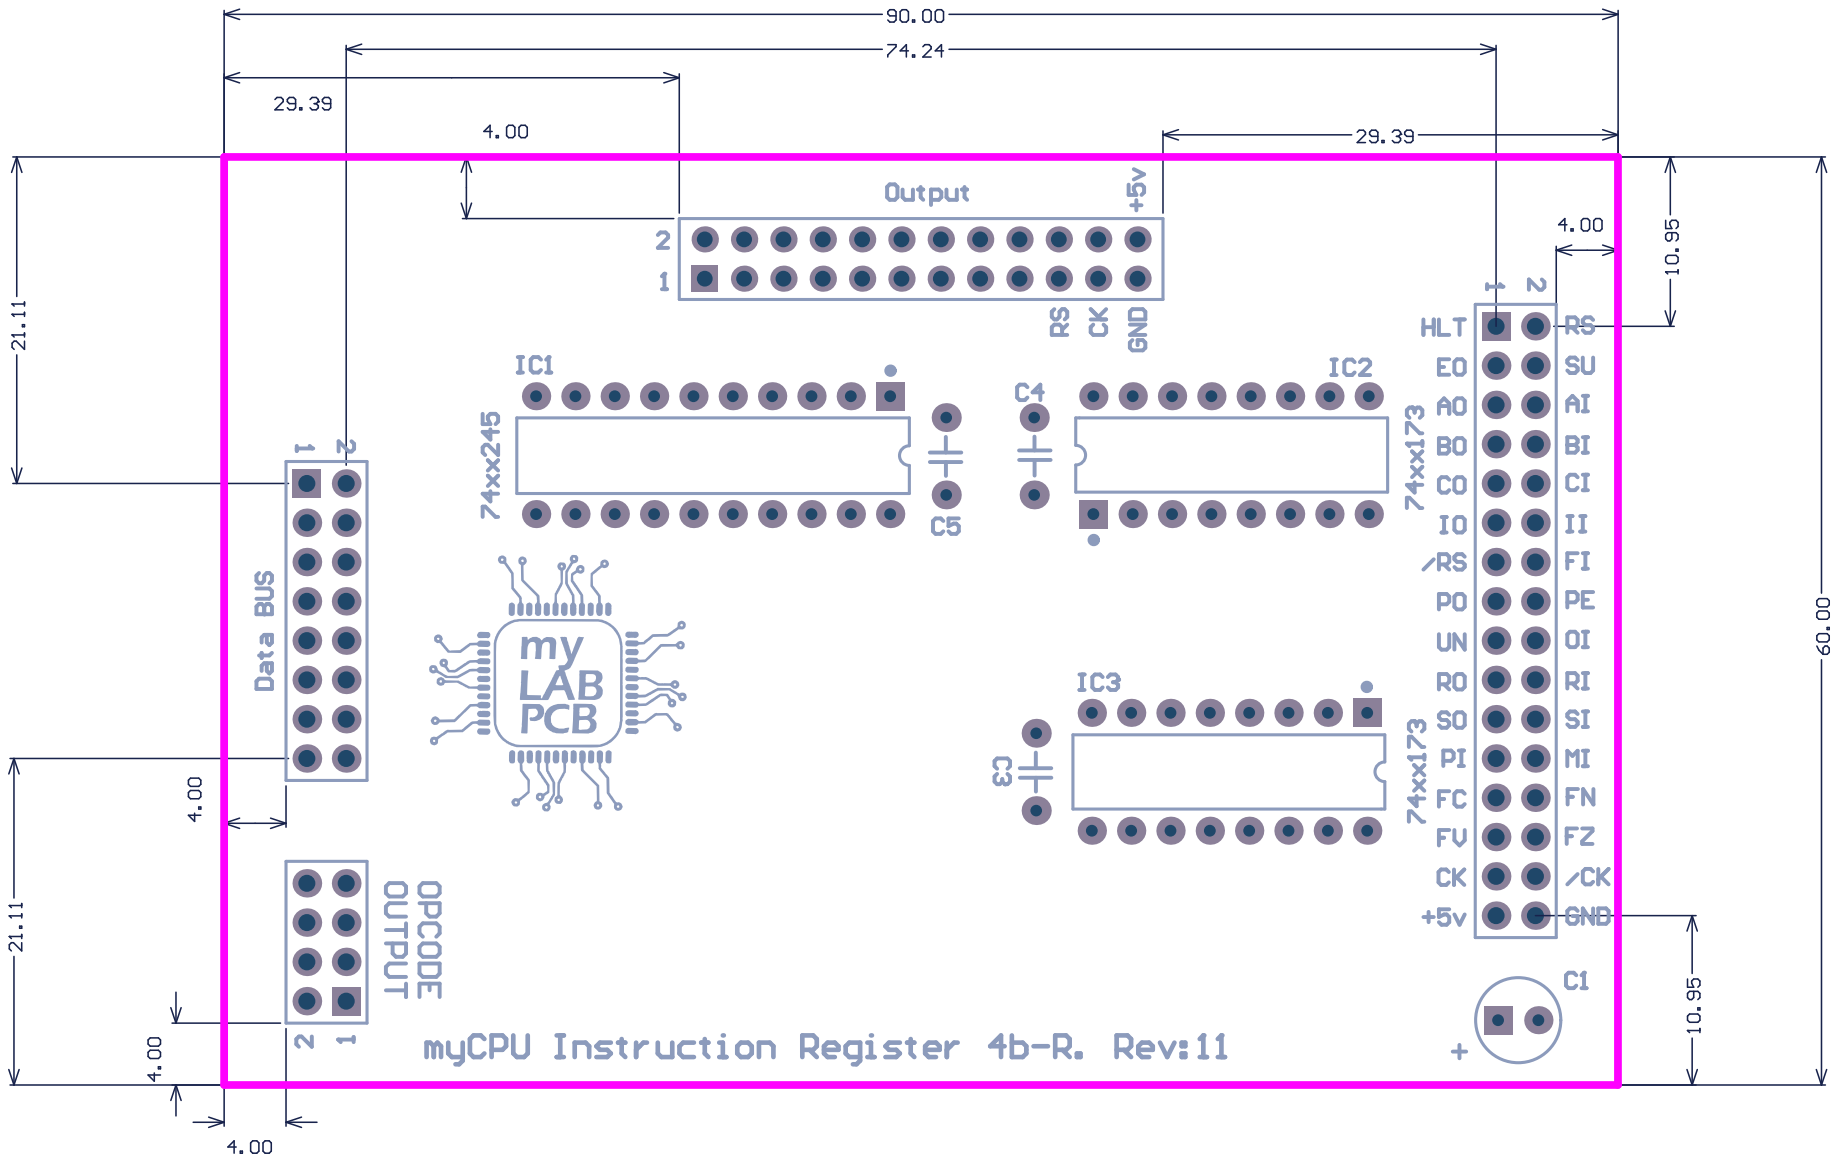
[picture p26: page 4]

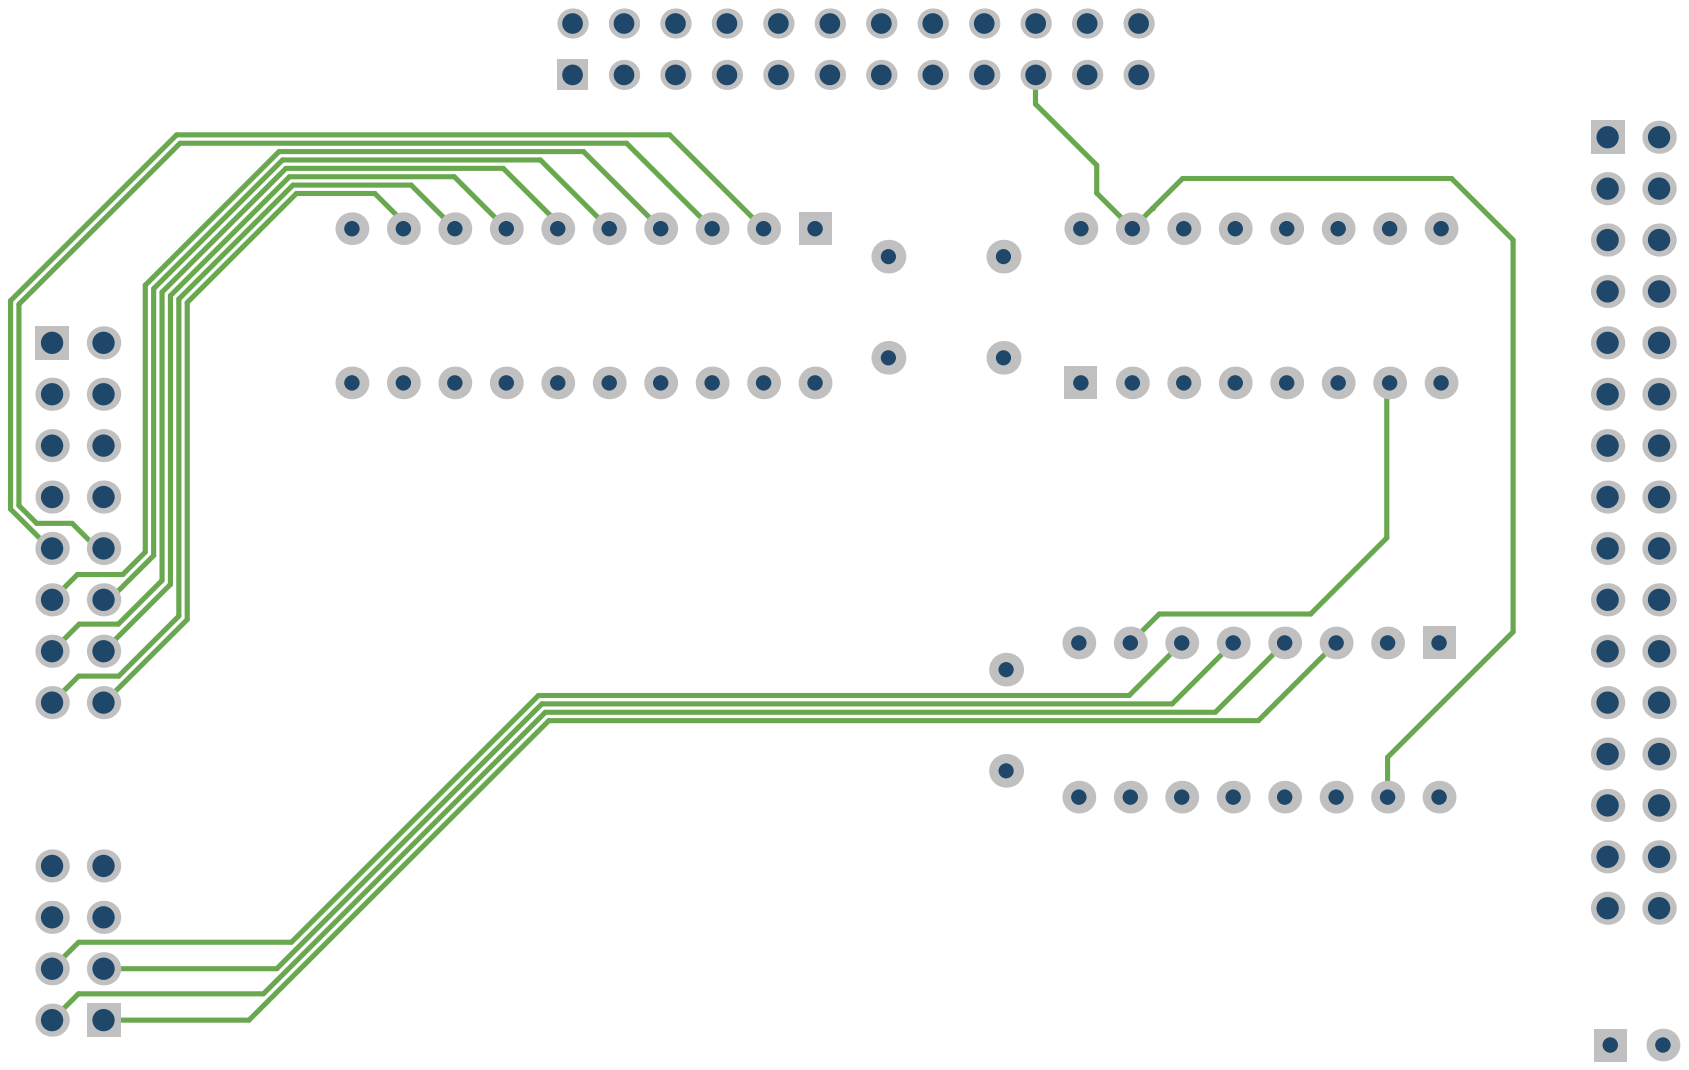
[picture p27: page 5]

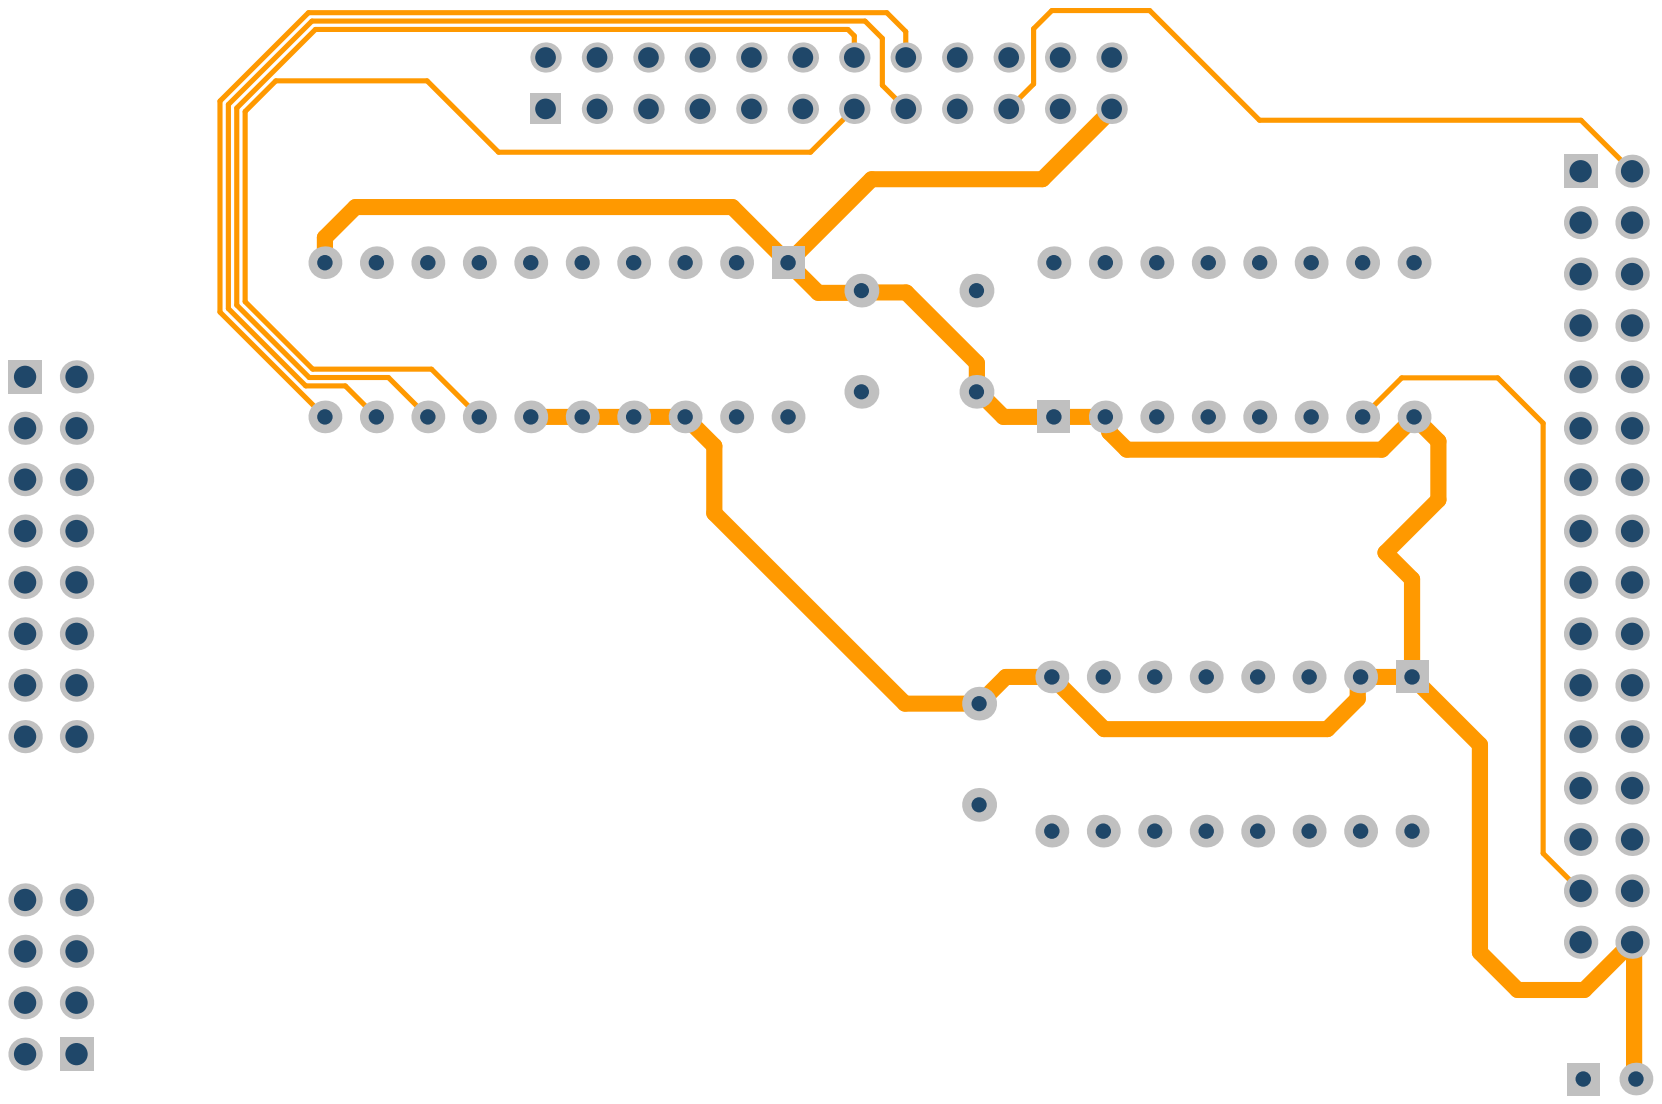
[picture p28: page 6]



# Bill of Materials

# myCPU Instruction Register 4+4 bit

Description | Value | Q
Electrolytic capacitor 16v/50v | 10µF | 1
Ceramic capacitor | 100nF | 3
Non inverting bus transceiver | 74xx245 | 1
4-bit D-Type Register with 3 state outputs | 74xx173 | 2
Pin Header, THT, pitch 2.54mm, Dual Row, Vertical | 16p | 1
Pin Header, THT, pitch 2.54mm, Dual Row, Vertical | 32p | 1
Socket Header, THT, pitch 2.54mm, Dual Row, Vertical | 24p | 1
Pin Header, THT, pitch 2.54mm, Dual Row, Vertical | 8p | 1

# Assembly List

# myCPU Instruction Register 4+4 bit

Designator | Description | Value
C1 | Electrolytic capacitor 16v/50v | 10µF
C3 | Ceramic capacitor | 100nF
C4 | Ceramic capacitor | 100nF
C5 | Ceramic capacitor | 100nF
IC1 | Non inverting bus transceiver | 74xx245
IC2 | 4-bit D-Type Register with 3 state outputs | 74xx173
IC3 | 4-bit D-Type Register with 3 state outputs | 74xx173
P1 | Pin Header, THT, pitch 2.54mm, Dual Row, Vertical | 16p
P2 | Pin Header, THT, pitch 2.54mm, Dual Row, Vertical | 32p
P3 | Socket Header, THT, pitch 2.54mm, Dual Row, Vertical | 24p
P6 | Pin Header, THT, pitch 2.54mm, Dual Row, Vertical | 8p

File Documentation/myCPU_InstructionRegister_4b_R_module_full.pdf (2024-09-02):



A 4+4 bits register module. Most
significative word correspond to
instruction opcode and is shared
with Instruction decoder, less
operand and is exposed to data BUS
when an IO signal is received. Bit
weigth goes from Q8 (less) to Q1
(most)

Project: myCPU Instruction Register 4+4 bit R






# Bill of Materials

# myCPU Instruction Register 4+4 bit

Description | Value | Q
Electrolytic capacitor 16v/50v | 10µF | 1
Ceramic or tantalum capacitor | 100nF | 3
Non inverting bus transceiver | 74xx245 | 1
4-bit D-Type Register with 3 state outputs | 74xx173 | 2
Pin Header, THT, pitch 2.54mm, Dual Row, Vertical, 16p | 16p | 1
Pin Header, THT, pitch 2.54mm, Dual Row, Vertical, 32p | 32p | 1
Socket Header, THT, pitch 2.54mm, Dual Row, Vertical, 24p | 24p | 1
Pin Header, THT, pitch 2.54mm, Dual Row, Vertical, 8p | 8p | 1

# Assembly List

## myCPU Instruction Register 4+4 bit

Designator | Description | Value
C1 | Electrolytic capacitor 16v/50v | 10µF
C3 | Ceramic or tantalum capacitor | 100nF
C4 | Ceramic or tantalum capacitor | 100nF
C5 | Ceramic or tantalum capacitor | 100nF
IC1 | Non inverting bus transceiver | 74xx245
IC2 | 4-bit D-Type Register with 3 state outputs | 74xx173
IC3 | 4-bit D-Type Register with 3 state outputs | 74xx173
P1 | Pin Header, THT, pitch 2.54mm, Dual Row, Vertical, 16p | 16p
P2 | Pin Header, THT, pitch 2.54mm, Dual Row, Vertical, 32p | 32p
P3 | Socket Header, THT, pitch 2.54mm, Dual Row, Vertical, 24p | 24p
P6 | Pin Header, THT, pitch 2.54mm, Dual Row, Vertical, 8p | 8p

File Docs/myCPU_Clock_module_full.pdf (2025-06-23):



Control the duty cycle of the
clock signal using R1.
Without an oscilloscope use a
common value of 270Ω

Project: myCPU Clock module

Control debouncing
threshold of push button
using a right combination






# Bill of Materials

## myCPU Clock

Description | Value | Q
555 Timer | 555 | 3
Ceramic capacitor | 10nF | 3
Ceramic capacitor | 470nF | 1
Ceramic capacitor | 100nF | 6
Electrolytic capacitor 16v/50v | 10µF | 1
Electrolytic capacitor 16v/50v | 0.22µF | 1
Hex inverters | 74xx04 | 1
Led 5mm Round | Red | 1
Led 5mm Round | Green | 1
Mini slide switch 2 pos, 3 pins | SP2T | 1
Pin Header, THT, pitch 2.54mm, Dual Row, Vertical | 16p | 1
Pin Header, THT, pitch 2.54mm, Dual Row, Vertical | 32p | 1
Pin Header, THT, pitch 2.54mm, Single Row, Vertical | 4p | 1
Potentiometer vertical, rotary, 3pins | 1M | 1
Quad 2-input AND gates | 74xx08 | 1
Quad 2-input OR gates. | 74xx32 | 1
Resistor Axial | 1K | 4
Resistor Axial | 220 | 2
Resistor Axial | 4.7K | 2
Resistor Axial | 330 | 1
Tactile button 12 mm | 12mm | 1
Trimmer resistor 3 pin | 1K | 1
Vertical variable resistor 3 pins | 1M | 1

# Assembly List

## myCPU Clock

Designator | Description | Value
C1 | Electrolytic capacitor 16v/50v | 10µF
C4 | Electrolytic capacitor 16v/50v | 0.22µF
C5 | Ceramic capacitor | 10nF
C6 | Ceramic capacitor | 10nF
C7 | Ceramic capacitor | 470nF
C8 | Ceramic capacitor | 10nF
C9 | Ceramic capacitor | 100nF
C10 | Ceramic capacitor | 100nF
C11 | Ceramic capacitor | 100nF
C12 | Ceramic capacitor | 100nF
C13 | Ceramic capacitor | 100nF
C14 | Ceramic capacitor | 100nf
D1 | Led 5mm Round | Red
D2 | Led 5mm Round | Green
IC1 | 555 Timer | 555
IC2 | 555 Timer | 555
IC3 | 555 Timer | 555
IC4 | Hex inverters | 74xx04
IC5 | Quad 2-input OR gates. | 74xx32
IC6 | Quad 2-input AND gates | 74xx08
P1 | Pin Header, THT, pitch 2.54mm, Dual Row, Vertical | 16p
P2 | Pin Header, THT, pitch 2.54mm, Dual Row, Vertical | 32p
POT1 | Potentiometer vertical, rotary, 3pins | 1M
R1 | Trimmer resistor 3 pin | 1K
R2 | Resistor Axial | 1K
R3 | Vertical variable resistor 3 pins | 1M
R4 | Resistor Axial | 1K
R5 | Resistor Axial | 1K
R6 | Resistor Axial | 1K
R7 | Resistor Axial | 220
R8 | Resistor Axial | 220
R9 | Resistor Axial | 4.7K
R10 | Resistor Axial | 4.7K
R12 | Resistor Axial | 330
SW1 | Mini slide switch 2 pos, 3 pins | SP2T
T1 | Pin Header, THT, pitch 2.54mm, Single Row, Vertical | 4p
TACT1 | Tactile button 12 mm | 12mm

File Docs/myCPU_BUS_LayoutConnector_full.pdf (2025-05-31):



Project: myCPU Layout Connector module


# Bill of Materials

# myCPU Layout Connector

Description | Value | Q
Ceramic capacitor | 100nF | 1
Electrolytic capacitor 16v/50v | 330µF | 2
1N5817 or 1N4007 | 1N5817 | 1
Pin Header, THT, pitch 2.54mm, Dual Row, Angled | 32p | 2
Pin Header, THT, pitch 2.54mm, Dual Row, Angled | 16p | 2
DC Power Jack, 2.5 A, 2mm Center Pin, 3 Position | 2mm 3p | 1
Mini slide switch SP2T 2mm ANGLED | SP2T | 1

# Assembly List

## myCPU Layout Connector

Designator | Description | Value
C1 | Ceramic capacitor | 100nF
C2 | Electrolytic capacitor 16v/50v | 330µF
C3 | Electrolytic capacitor 16v/50v | 330µF
D1 | 1N5817 or 1N4007 | 1N5817
P1 | Pin Header, THT, pitch 2.54mm, Dual Row, Angled | 32p
P2 | Pin Header, THT, pitch 2.54mm, Dual Row, Angled | 16p
P3 | Pin Header, THT, pitch 2.54mm, Dual Row, Angled | 16p
P4 | Pin Header, THT, pitch 2.54mm, Dual Row, Angled | 32p
PWR_JACK1 | DC Power Jack, 2.5 A, 2mm Center Pin, 3 Position | 2mm 3p
SW1 | Mini slide switch SP2T 2mm ANGLED | SP2T

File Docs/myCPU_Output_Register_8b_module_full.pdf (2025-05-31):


Control BUS Connector | OUTPUT Connector | Data BUS Connector


Project: myCPU Output Register 8 bit






# Bill of Materials

# myCPU Output Register 8 bit

Description | Value | Q
Electrolytic capacitor 16v/50v | 10µF | 1
Ceramic capacitor | 100nF | 2
4-bit D-Type Register with 3 state outputs | 74xx173 | 2
Pin Header, THT, pitch 2.54mm, Dual Row, Vertical | 16p | 1
Pin Header, THT, pitch 2.54mm, Dual Row, Vertical | 32p | 1
Socket Header, THT, pitch 2.54mm, Dual Row, Vertical | 24p | 1

# Assembly List

# myCPU Output Register 8 bit

Designator | Description | Value
C1 | Electrolytic capacitor 16v/50v | 10µF
C2 | Ceramic capacitor | 100nF
C3 | Ceramic capacitor | 100nF
IC1 | 4-bit D-Type Register with 3 state outputs | 74xx173
IC2 | 4-bit D-Type Register with 3 state outputs | 74xx173
P1 | Pin Header, THT, pitch 2.54mm, Dual Row, Vertical | 16p
P2 | Pin Header, THT, pitch 2.54mm, Dual Row, Vertical | 32p
P3 | Socket Header, THT, pitch 2.54mm, Dual Row, Vertical | 24p

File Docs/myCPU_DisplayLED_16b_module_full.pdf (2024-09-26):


## INPUT Data Connector

I12


Feel free to choose the value of the limiting
resistors to adjust the balanced brightness
of the leds. Depending of the color you may
have to use different values for the limiting
resitors.

Project: myCPU Display LED 16 bit




# Bill of Materials

# myCPU Display LED 16 bit

Description | Value | Q
Led Bar 8 segments, DIP 16 | 8 seg | 2
Pin Header, THT, pitch 2.54mm, Dual Row, Vertical | 24p | 1
Resistor array 8 elements,9 pins | 2.2K | 2

# Assembly List

# myCPU Display LED 16 bit

Designator | Description | Value
LB1 | Led Bar 8 segments, DIP 16 | 8 seg
LB2 | Led Bar 8 segments, DIP 16 | 8 seg
P1 | Pin Header, THT, pitch 2.54mm, Dual Row, Vertical | 24p
RN1 | Resistor array 8 elements,9 pins | 2.2K
RN2 | Resistor array 8 elements,9 pins | 2.2K

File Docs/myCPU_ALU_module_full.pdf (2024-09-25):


Control BUS Connector | OUTPUT Connector | Data BUS Connector
Register A input | Register B Input


Input significative bit
weigh goes from IA7 or YB7
(lower) to IA0 or YB0
(higher)

Operation goes from E1 to E4 and
carry is passed from C4 to C0.
The ADDER inputs order goes from
Cascade is from IC3 to IC2.

CO pin, initial carry should set to SU
signal. On ADD operation SU is LOW and Carry
is 0, for SUB operation SU is HIGH and Carry
becames 1 to accomplish two'complement binary
representation.

Project: myCPU ALU module






# Bill of Materials

# myCPU ALU module

Description | Value | Q
Electrolytic capacitor 16v/50v | 10µF | 1
Ceramic capacitor | 100nF | 7
Non inverting bus transceiver | 74xx245 | 1
4-Bits Full adder with fast carry | 74xx283 | 2
Quad 2-input XOR gates | 74xx86 | 2
Quad 2-input NOR gates | 74xx02 | 1
Quad 2-input AND gates | 74xx08 | 1
Pin Header, THT, pitch 2.54mm, Dual Row, Vertical | 16p | 1
Pin Header, THT, pitch 2.54mm, Dual Row, Vertical | 32p | 1
Socket Header, THT, pitch 2.54mm, Dual Row, Vertical | 24p | 1
Pin Header, THT, pitch 2.54mm, Dual Row, Vertical | 8p | 2
Resistor Axial | 4.7K | 1

# Assembly List

# myCPU ALU module

Designator | Description | Value
C1 | Electrolytic capacitor 16v/50v | 10µF
C2 | Ceramic capacitor | 100nF
C3 | Ceramic capacitor | 100nF
C4 | Ceramic capacitor | 100nF
C5 | Ceramic capacitor | 100nF
C6 | Ceramic capacitor | 100nF
C7 | Ceramic capacitor | 100nF
C8 | Ceramic capacitor | 100nF
IC1 | Non inverting bus transceiver | 74xx245
IC2 | 4-Bits Full adder with fast carry | 74xx283
IC3 | 4-Bits Full adder with fast carry | 74xx283
IC4 | Quad 2-input XOR gates | 74xx86
IC5 | Quad 2-input XOR gates | 74xx86
IC6 | Quad 2-input NOR gates | 74xx02
IC7 | Quad 2-input AND gates | 74xx08
P1 | Pin Header, THT, pitch 2.54mm, Dual Row, Vertical | 16p
P2 | Pin Header, THT, pitch 2.54mm, Dual Row, Vertical | 32p
P3 | Socket Header, THT, pitch 2.54mm, Dual Row, Vertical | 24p
P5 | Pin Header, THT, pitch 2.54mm, Dual Row, Vertical | 8p
P6 | Pin Header, THT, pitch 2.54mm, Dual Row, Vertical | 8p
R1 | Resistor Axial | 4.7K

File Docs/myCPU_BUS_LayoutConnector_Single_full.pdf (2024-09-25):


Revision: 3; Date: 19-Sep-24; GND; PWR_JACK1; Power Supply; /CLK; RST; CLK; /RST; HLT

Project: myCPU Single Layout Connector

Author: Rafa Hernández




# Bill of Materials

## myCPU Single Layout Connector

Description | Value | Q
Ceramic capacitor | 100nF | 1
Electrolytic capacitor 16v/50v | 330µF | 2
1N5817 or 1N4007 | 1N5817 | 1
Pin Header, THT, pitch 2.54mm, Dual Row, Angled | 32p | 1
Pin Header, THT, pitch 2.54mm, Dual Row, Angled | 16p | 1
DC Power Jack, 2.5 A, 2mm Center Pin, 3 Position | 2mm 3p | 1
Mini slide switch SP2T 2mm ANGLED | SP2T | 1

# Assembly List

## myCPU Single Layout Connector

Designator | Description | Value
C1 | Ceramic capacitor | 100nF
C2 | Electrolytic capacitor 16v/50v | 330µF
C3 | Electrolytic capacitor 16v/50v | 330µF
D1 | 1N5817 or 1N4007 | 1N5817
P1 | Pin Header, THT, pitch 2.54mm, Dual Row, Angled | 32p
P2 | Pin Header, THT, pitch 2.54mm, Dual Row, Angled | 16p
PWR_JACK1 | DC Power Jack, 2.5 A, 2mm Center Pin, 3 Position | 2mm 3p
SW1 | Mini slide switch SP2T 2mm ANGLED | SP2T

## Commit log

2022-01-03 Add pcb documentation and folder
2022-01-03 Add CAD folder and files
    [Handle180.stl, Handle85.stl, PCBModulesBox.stl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]
2022-01-03 Add instruction decode template
    [myCPU_Microinstructions.xlsx]
2022-01-03 Remove instruction template xlsx and add zip file instead
    [myCPU_Microinstructions.xlsx]
2022-03-10 Update files
    [Display_Separator v19.stl, myCPU_Full_BOM_List.xlsx, myCPU_Full_BOM_List_Rounded.xlsx]
2022-05-06 Upload updated documentation and files
    [myCPU_Full_BOM_List.xlsx, myCPU_Full_BOM_List_Rounded.xlsx, myCPU_microprogramming.xlsx]
2022-05-06 Update BOM Lists
    [myCPU_Full_BOM_List.xlsx, myCPU_Full_BOM_List_Rounded.xlsx]
2023-01-14 Update templates
    [myCPU_microprogramming.xlsx]
2023-01-14 Update CAD files
    [Extractor_42.stl, Extractor_42_40 v2.stl, Unplugger.stl]
2023-08-02 Update Encoder CLI v1.3.0 all platforms with source and binary files
2023-08-02 Update CADFiles zip
    [Display_Separator v19.stl, Extractor_42.stl, Extractor_42_40 v2.stl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]
2023-08-02 Update folder structure
    [myCPU_Templates.xlsx]
2023-08-24 Update Arduino encoder programs
2023-08-24 Update Encoder CLI filename
2024-04-17 Update BOM file
2024-05-04 Update Arduino microinstructions EEProm programmer
2024-05-04 Changes in folders
    [myCPU_Templates.xlsx]
2024-05-27 Update encoders all platforms
2024-09-20 Upload code encoderCLI
2024-09-23 Update myCPU16 BOM list
2024-09-23 Remove Full BOM pdf
2024-09-26 Update encoderCLI location
2024-09-26 Add software folder and move encoderCLI
2024-09-26 Update readme files at Software and encoderCLI
2024-09-26 Update readme encoderCLI
2024-09-28 Add gerber sample file
2024-09-28 Change gerber sample file name
2024-10-01 Remove sample gerber
2024-10-04 Add Cad, BOM, Altium libraries
    [Display16_Separator.stl, Display4D_Separator.stl, Display8_Separator.stl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]
2024-10-04 Rename cad files zip
2024-11-11 Add microprogramming template
    [myCPU_microprogramming.xlsx]
2024-11-11 Update microprogramming template
    [myCPU_Microprogramming_Tpl.xlsx, myCPU_microprogramming.xlsx]
